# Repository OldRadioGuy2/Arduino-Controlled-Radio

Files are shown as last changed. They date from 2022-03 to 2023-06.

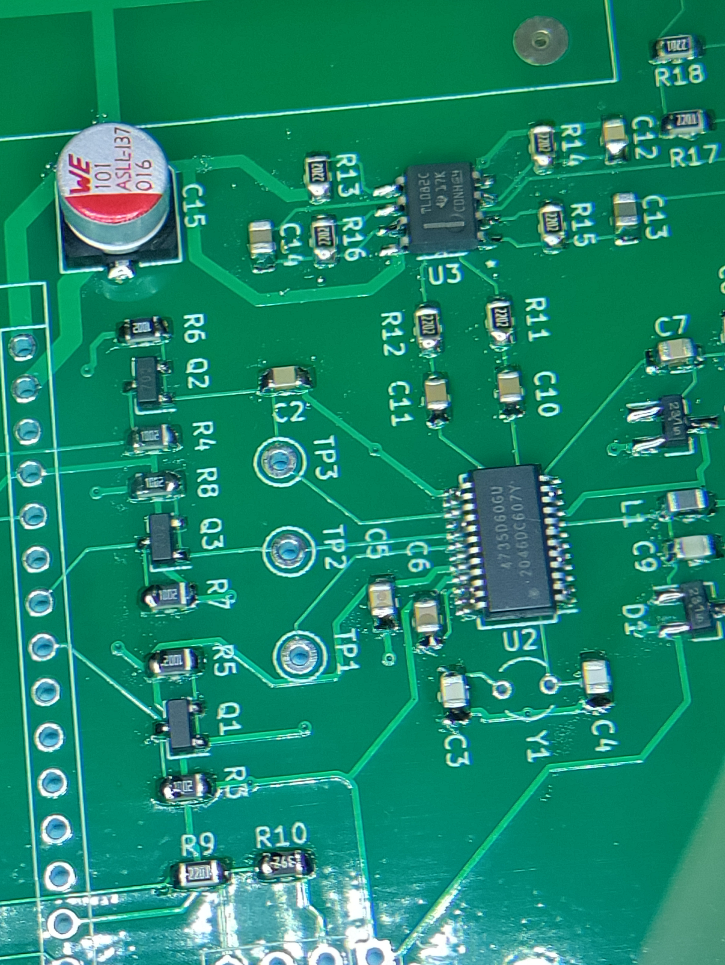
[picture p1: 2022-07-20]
Hardware/IMG_20220409_145141.jpg

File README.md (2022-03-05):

# Arduino-Controlled-Radio
An Arduino Controlled SI47xx Radio

This repository contains code and hardware design for an Arduino controlled radio based on the Skyworks SI47xx series of integrated radios, particularly the SI4735.

This particular implementation was concieved as a "behind the scenes" replacement for antique radio chassis that are too far gone for refurbishing. The idea is to use the Arduino to "read" the radio's original controls and translate their volume, tuning, and band settings to the SI chip. An NE55C is used to translate the tuning capacitor setting to a pulse width. A BLE Bluetooth module is included so that configuration, calibration, and remote control can be done using a smartphone application. Finally, the audio output is buffered for stero headphone use or amplified using an on-board LM1875 to drive a speaker.

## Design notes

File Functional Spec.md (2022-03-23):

# Arduino Controlled Radio Functional Specification
## Introduction
The Arduino Controlled Radio can be used for a variety of purposes but it's primary use case is to replace the electronics of a "worn out" vintage radio while
maintaining the radio's user controls. The Arduino determines the positions of the tuning capacitor, volume control, and band switch (if any) and translates them
into commands that are sent to the Si4735 AM/SW/FM receiver IC. The output of the IC is buffered for use with headphones or external stereo amplifier while an 
optional Class D amplifier module provides sufficient power to drive a modern speaker placed in the cabinet.

In addition to responding to the radios controls, the Arduino also monitors the serial port and a Bluetooth receiver for various commands so that the board can be configured and operated from a PC or Android/iPhone acting as a "remote control."

## Hardware
The hardware consists of the following major components:

- An Arduino Nano processor
- An HC-06 Bluetooth receiver
- A Skyworks SI4735 AM/SW/FM receiver IC
- A TL082 based stereo headphone buffer amplifier
- A TPA3118 based class D monophonic amplifier module (multi-sourced)

### Arduino Nano I/O
Arduino pins D3-D9 and A0-A3 are brought out to the board edge as I/O resources. An additional input is used to determine the position of the host radio's tuning dial by measuring value of the variable capacitor using an NE555C as a timer in one-shot mode with the capacitor controlling the pulse time. D13 triggers the one shot and A7 is used as a digital input to measure the pulse width.

D11(TxD out) and D12(RxD in) are used as a software serial port to communicate with the HC-06.

A4(SDIO) and A5(SCLK) are used as an I2C interface to the SI4735 while D2 is the  device reset.

### HC-06
The HC-06 is a slave only Bluetooth receiver with a serial interface that defaults to 9600 Baud. The module supports a limited AT command set. Of interest to us:

- **Set Name:**  *AT+NAMEnewname* sets the Bluetooth device name. This should return *OKnewname*
- **AT+PINxxxx:** *AT+PINxxxx* sets the pairing pin. This should return *OKxxxx*

### SI4735
The SI4735 is a general purpose single chip receiver with a number of features:  
  
- Worldwide FM band support (64–108 MHz)
- Worldwide AM band support (520–1710 kHz)
- SW band support (2.3–26.1 MHz)
- LW band support (153–279 kHz)
- Excellent real-world performance
- Freq synthesizer with integrated VCO
- Advanced seek tuning
- Automatic frequency control (AFC)
- Automatic gain control (AGC)
- Digital FM stereo decoder
- Programmable AVC max gain
- Programmable de-emphasis
- Seven selectable AM channel filters
- AM/FM/SW/LW digital tuning
- Programmable reference clock
- Volume control
- Adjustable soft mute control
- RDS/RBDS processor (Si4735)
- Optional digital audio out (Si4735)
- 2-wire and 3-wire control interface
- Wide range of ferrite loop sticks and
air loop antennas supported

It has an extensive programming command set which can be found here:
https://www.skyworksinc.com/-/media/Skyworks/SL/documents/public/application-notes/AN332.pdf

This project will use a (possibly modified) version of the interface library written in 2019 by Ricardo Lima Caratti.

## Software
The Software Consists of the following primary components:  
  
- **Setup:** Initializes the hardware, loads the stored configuration
- **Loop:** Performs the repetitive tasks needed to implement the following functionality:
    + **Check the tuner position (if enabled):** trigger and time the NE555C. Calculate the current position using the stored calibration points. If changed from last reading by more than the (band dependent) threshold, update the receiver frequency.
	+ **Check volume control (if enabled):** Read the configured Analog input and convert to position. If changed more than the threshold, update the volume.
	+ **Check the band switch (if enabled):** The bandswitch will be wired as a voltage divider so that each position will register a discrete voltage. Read the configured Analog input and convert to band #. Get the current band parameters from the configuration store.
	+ **Check the Arduino Serial Port for a command: ** If one was received call the *Command Processor*
	+ **If the Bluetooth receiver is paired, check its Serial Port for a command: ** If one was received call the *Command Processor*.
- **Command Processor:** Translates the received commands into actions. The key action classes are:
	+ **Get/Set SI4735 parameter:** Examples include changing frequency, volume, band, etc.
	+ **Get/Set Configuration Parameter:** Examples include defining bands, features used, etc.
	+ **Calibrate:** Determine physical to internal conversions such as NE555C pulse width vs tuner position, voltage values for band switch, etc.
- **Storage Manager** - Get/Set parameters in non-volatile storage.

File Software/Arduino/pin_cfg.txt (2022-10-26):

Using a Bus Pirate for a BLE modem.

Nano Pin D12 -  gray MOSI/TX
Nano Pin D11 - black MISO/RX
Nano Ground  - brown GND

Enter:
m
3 (serial)
5 (9600)
1 (8 bit)
1 (1 stop)
1 (idle high)
2 (normal output)
W (power supplies on)
P (outputs enable)
(1) (UART bridge)
y

Adafruit ILI9341 display connection:

Nano Pin D9 - Clk
Nano Pin D8 - MISO
Nano Pin D7 - MOSI
Nano Pin D6 - CS
Nano Pin D5 - D/C
Nano Pin D4 - Rst (optional)

Nano Pin VIN - 5 Volts for display

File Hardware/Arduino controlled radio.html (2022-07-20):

# /home/afinger/Dropbox/Projects/Arduino-Controlled-Radio/Hardware/Arduino controlled radio.sch

Thu 24 Mar 2022 08:08:10 PM EDT

Eeschema 5.1.5+dfsg1-2build2

Component Count:59

Ref | Qnty | Value | Part | Footprint | Description | Vendor
A1 | 1 | Arduino_BLE_Nano | MCU_Module:Arduino_Nano_v3.x | Module:Arduino_Nano | Arduino Nano v3.x
C1 | 1 | .01uF | Device:C_Small | Capacitor_SMD:C_0805_2012Metric_Pad1.18x1.45mm_HandSolder | Unpolarized capacitor, small symbol
C2 | 1 | 10nF | Device:C_Small | Capacitor_SMD:C_0805_2012Metric_Pad1.18x1.45mm_HandSolder | Unpolarized capacitor, small symbol
C3, C4 | 2 | 22pf | Device:C_Small | Capacitor_SMD:C_0805_2012Metric_Pad1.18x1.45mm_HandSolder | Unpolarized capacitor, small symbol
C5 | 1 | 100nf | Device:C_Small | Capacitor_SMD:C_0805_2012Metric_Pad1.18x1.45mm_HandSolder | Unpolarized capacitor, small symbol
C6 | 1 | 22nf | Device:C_Small | Capacitor_SMD:C_0805_2012Metric_Pad1.18x1.45mm_HandSolder | Unpolarized capacitor, small symbol
C7 | 1 | .47uF | Device:C_Small | Capacitor_SMD:C_0805_2012Metric_Pad1.18x1.45mm_HandSolder | Unpolarized capacitor, small symbol
C8 | 1 | 33pF | Device:C_Small | Capacitor_SMD:C_0805_2012Metric_Pad1.18x1.45mm_HandSolder | Unpolarized capacitor, small symbol
C9 | 1 | 6.8pF | Device:C_Small | Capacitor_SMD:C_0805_2012Metric_Pad1.18x1.45mm_HandSolder | Unpolarized capacitor, small symbol
C10, C11 | 2 | 1uF | Device:C_Small | Capacitor_SMD:C_0805_2012Metric_Pad1.15x1.40mm_HandSolder | Unpolarized capacitor, small symbol
C12 | 1 | .1uF | Device:C_Small | Capacitor_SMD:C_0805_2012Metric_Pad1.15x1.40mm_HandSolder | Unpolarized capacitor, small symbol
C13, C14 | 2 | 10uF | Device:C_Small | Capacitor_SMD:C_0805_2012Metric_Pad1.15x1.40mm_HandSolder | Unpolarized capacitor, small symbol
C15 | 1 | 100uF | Device:CP1_Small | Capacitor_SMD:C_Elec_6.3x5.4 | Polarized capacitor, small US symbol
C16 | 1 | .1 uF | Device:C_Small | Capacitor_SMD:C_0805_2012Metric_Pad1.15x1.40mm_HandSolder | Unpolarized capacitor, small symbol
D1, D2 | 2 | CM1213A-01SO | Power_Protection:CM1213A-01SO | Package_TO_SOT_SMD:SOT-23_Handsoldering | Single Channel ESD Protection Array
J1 | 1 | Jack-DC | Connector:Jack-DC | Arduino controlled radio:CUI_PJ-202B | DC Barrel Jack
J2 | 1 | Conn_02x15_Odd_Even | Connector_Generic:Conn_02x15_Odd_Even | Connector_PinHeader_2.54mm:PinHeader_2x15_P2.54mm_Vertical | Generic connector, double row, 02x15, odd/even pin numbering scheme (row 1 odd numbers, row 2 even numbers), script generated (kicad-library-utils/schlib/autogen/connector/)
J3, J6 | 2 | Conn_01x02 | Connector_Generic:Conn_01x02 | Connector_PinHeader_2.54mm:PinHeader_1x02_P2.54mm_Vertical | Generic connector, single row, 01x02, script generated (kicad-library-utils/schlib/autogen/connector/)
J4 | 1 | HC-06 Connector | Connector_Generic:Conn_01x04 | Connector_PinSocket_2.54mm:PinSocket_1x04_P2.54mm_Vertical | Generic connector, single row, 01x04, script generated (kicad-library-utils/schlib/autogen/connector/)
J5 | 1 | Conn_Coaxial | Connector:Conn_Coaxial | Arduino controlled radio:CUI_RCJ-045 | coaxial connector (BNC, SMA, SMB, SMC, Cinch/RCA, ...)
J7 | 1 | SJ1-3525NG | Arduino Controlled Radio:SJ1-3525NG | Arduino controlled radio:CUI_SJ1-3525NG
J8 | 1 | Speaker | Connector:Conn_Coaxial | Arduino controlled radio:CUI_RCJ-045 | coaxial connector (BNC, SMA, SMB, SMC, Cinch/RCA, ...)
JP1 | 1 | Ext/Loop Antenna | Jumper:Jumper_3_Bridged12 | Connector_PinHeader_2.54mm:PinHeader_1x03_P2.54mm_Vertical | Jumper, 3-pole, pins 1+2 closed/bridged
L1 | 1 | 150nH | Device:L | Inductor_SMD:L_0805_2012Metric_Pad1.15x1.40mm_HandSolder | Inductor
L2 | 1 | 4.7uH | Device:L | Inductor_SMD:L_0805_2012Metric_Pad1.15x1.40mm_HandSolder | Inductor
Q1, Q2, Q3 | 3 | 2N7002 | Transistor_FET:2N7002 | Package_TO_SOT_SMD:SOT-23 | 0.115A Id, 60V Vds, N-Channel MOSFET, SOT-23
R1 | 1 | 2.2k | Device:R_Small_US | Resistor_SMD:R_0805_2012Metric_Pad1.20x1.40mm_HandSolder | Resistor, small US symbol
R2 | 1 | 1Meg | Device:R_Small_US | Resistor_SMD:R_0805_2012Metric_Pad1.15x1.40mm_HandSolder | Resistor, small US symbol
R3, R4, R5, R6, R7, R8 | 6 | 10K | Device:R_Small_US | Resistor_SMD:R_0805_2012Metric_Pad1.15x1.40mm_HandSolder | Resistor, small US symbol
R9 | 1 | 2.2K | Device:R_Small_US | Resistor_SMD:R_0805_2012Metric_Pad1.15x1.40mm_HandSolder | Resistor, small US symbol
R10 | 1 | 3.8K | Device:R_Small_US | Resistor_SMD:R_0805_2012Metric_Pad1.15x1.40mm_HandSolder | Resistor, small US symbol
R11, R12, R13, R14, R15, R16 | 6 | 22K | Device:R_Small_US | Resistor_SMD:R_0805_2012Metric_Pad1.15x1.40mm_HandSolder | Resistor, small US symbol
R17, R18 | 2 | 1K | Device:R_Small_US | Resistor_SMD:R_0805_2012Metric_Pad1.15x1.40mm_HandSolder | Resistor, small US symbol
U1 | 1 | NE555 | Timer:NE555 | Arduino controlled radio:SOIC-8N | Precision Timers, DIP-8/SOIC-8
U2 | 1 | Si4735-D60-GU | RF_AM_FM:Si4735-D60-GU | Package_SO:SSOP-24_3.9x8.7mm_P0.635mm | AM/FM/SW/LW Broadcast Radio Receiver with RDS/RBDS
U3 | 1 | LM358 | Amplifier_Operational:LM358 | Arduino controlled radio:TL082CDR | Low-Power, Dual Operational Amplifiers, DIP-8/SOIC-8/TO-99-8
U4 | 1 | TPA3118AmplifierBoard | Arduino Controlled Radio:TPA3118AmplifierBoard | Arduino controlled radio:TPA3118_Board
Y1 | 1 | 32768KHz | Device:Crystal_Small | Crystal:Crystal_AT310_D3.0mm_L10.0mm_Vertical | Two pin crystal, small symbol

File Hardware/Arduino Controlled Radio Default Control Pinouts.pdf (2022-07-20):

Sheet1

## Arduino Controlled Radio Default Pinout

Connector Pins
Function Arduino Pin | Input
Tuning | | 27
Volume | A0 | 25 | Top of control to +5, bottom to GND, center to input
Band | A1 | 23

+5 pins are 18,22,26
GND pins are 2,4,5,6,10,12,14,16,20,24,28,30

Odd pins are nearest board edge

D13 Trigger
D10 Input

Top of control to +5, bottom to GND, wiper to input for 2 band, use voltage divider for multiple bands

Sheet1

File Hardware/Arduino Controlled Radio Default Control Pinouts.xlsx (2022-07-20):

Arduino Controlled Radio Default Pinout
 |  | Connector Pins
Function | Arduino Pin | Input
Tuning | D13 Trigger D10 Input | 27
Volume | A0 | 25 | Top of control to +5, bottom to GND, center to input
Band | A1 | 23 | Top of control to +5, bottom to GND, wiper to input for 2 band, use voltage divider for multiple bands
+5 pins are 18,22,26
GND pins are 2,4,5,6,10,12,14,16,20,24,28,30
Odd pins are nearest board edge

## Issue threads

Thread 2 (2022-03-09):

adding features for Arduino

LyleDriverGuy, 2022-03-09:
Reading a variable capacitor and controlling the receive frequency can be added to the main loop alongside the debug interface.

A global variable for new modes should be set and cleared with commands to the debug interface.  The mode can default to 'on' when it's ready to install.

The Bluetooth interface will share the serial port which will require changes to the debug interface.

OldRadioGuy2, 2022-03-10:
I need to update the schematic PDF for you. The Bluetooth is on a software serial port so no changes are needed for download and debug.

Agree on reading the cap. I think the main loop should be:
1. Check main serial port for command
2. Check the bluetooth for command
3. If enabled, check the capacitor position

There's a lot to control besides the frequency so we need to come up with a command set to access the chip functions via the SI4735 library.  Initially we can debug via the main serial port and then move to Bluetooth when the client is available.

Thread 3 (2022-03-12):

Audio Speaker Amplifier

OldRadioGuy2, 2022-03-12:
Going over the design once more, I realized that the LM1875 is not spec'ed below 16Volts so we can't expect much output. Some  alternatives:
1. Leave the amp off altogether and use an external unit or module. Downside: added cost expensive and need for additional power source.
2. Use a low voltage analog device like an LM386. Simple but downside is that you only get about 2Watts out at 12V
3. Use a Class D amp like a  TPA3111D1. Get good performance but design and board layout is more complicated to avoid noise issues.
4. Use a Class D amp module like: https://smile.amazon.com/gp/product/B07Q6RGVHQ. They seem to be multi-sourced from China but I'm not sure how stable the supply will be.

Thoughts? Any other alternatives?

lenlong36, 2022-03-13:
Alan,

Yes.  There are available inexpensive DC to DC converters that are very
small that you might be able to use. Amazon.com: ACEIRMC 3pcs XL6019 5A
High Power Current DC to DC Step-up 5V 6V 12V 24V 3-35V to 5-40V XL6019
Converter Adjustable Voltage Regulator Power Modules Boost Module Booster
(3pcs) : Electronics
<https://www.amazon.com/Aceirmc-Current-Converter-Adjustable-Regulator/dp/B082XQC2DS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>

Len

***@***.*** ***@***.***>*

On Fri, Mar 11, 2022 at 9:48 PM OldRadioGuy2 ***@***.***>
wrote:

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

OldRadioGuy2, 2022-03-14:
DC to DC converters and Class D amplifiers both risk introducing RF interference into the board. I've got some class D modules coming on Tuesday and I'll see whether they're a noise problem.

lenlong36, 2022-03-14:
It sure is a possibility.  I bought a 90vdc and 3vdc model and no noise on
the Hallicrafters receeiver.

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

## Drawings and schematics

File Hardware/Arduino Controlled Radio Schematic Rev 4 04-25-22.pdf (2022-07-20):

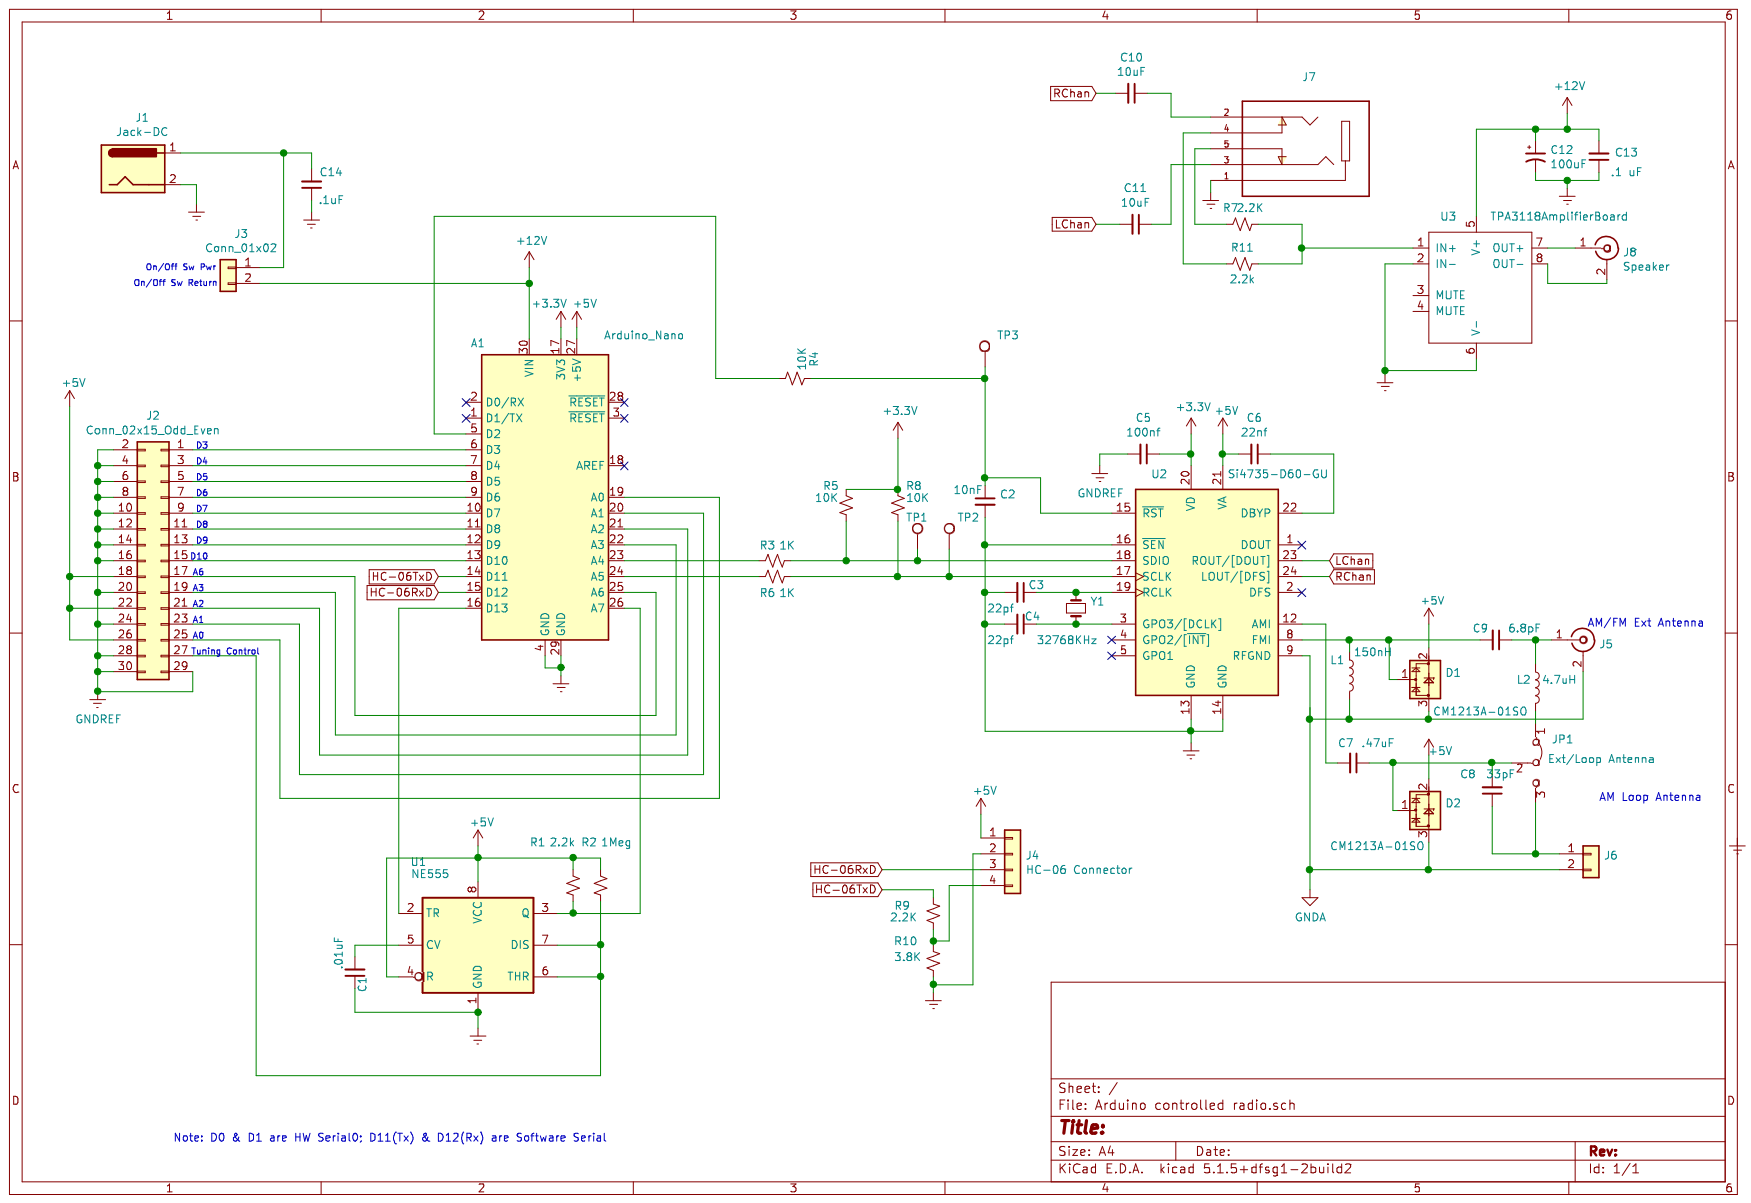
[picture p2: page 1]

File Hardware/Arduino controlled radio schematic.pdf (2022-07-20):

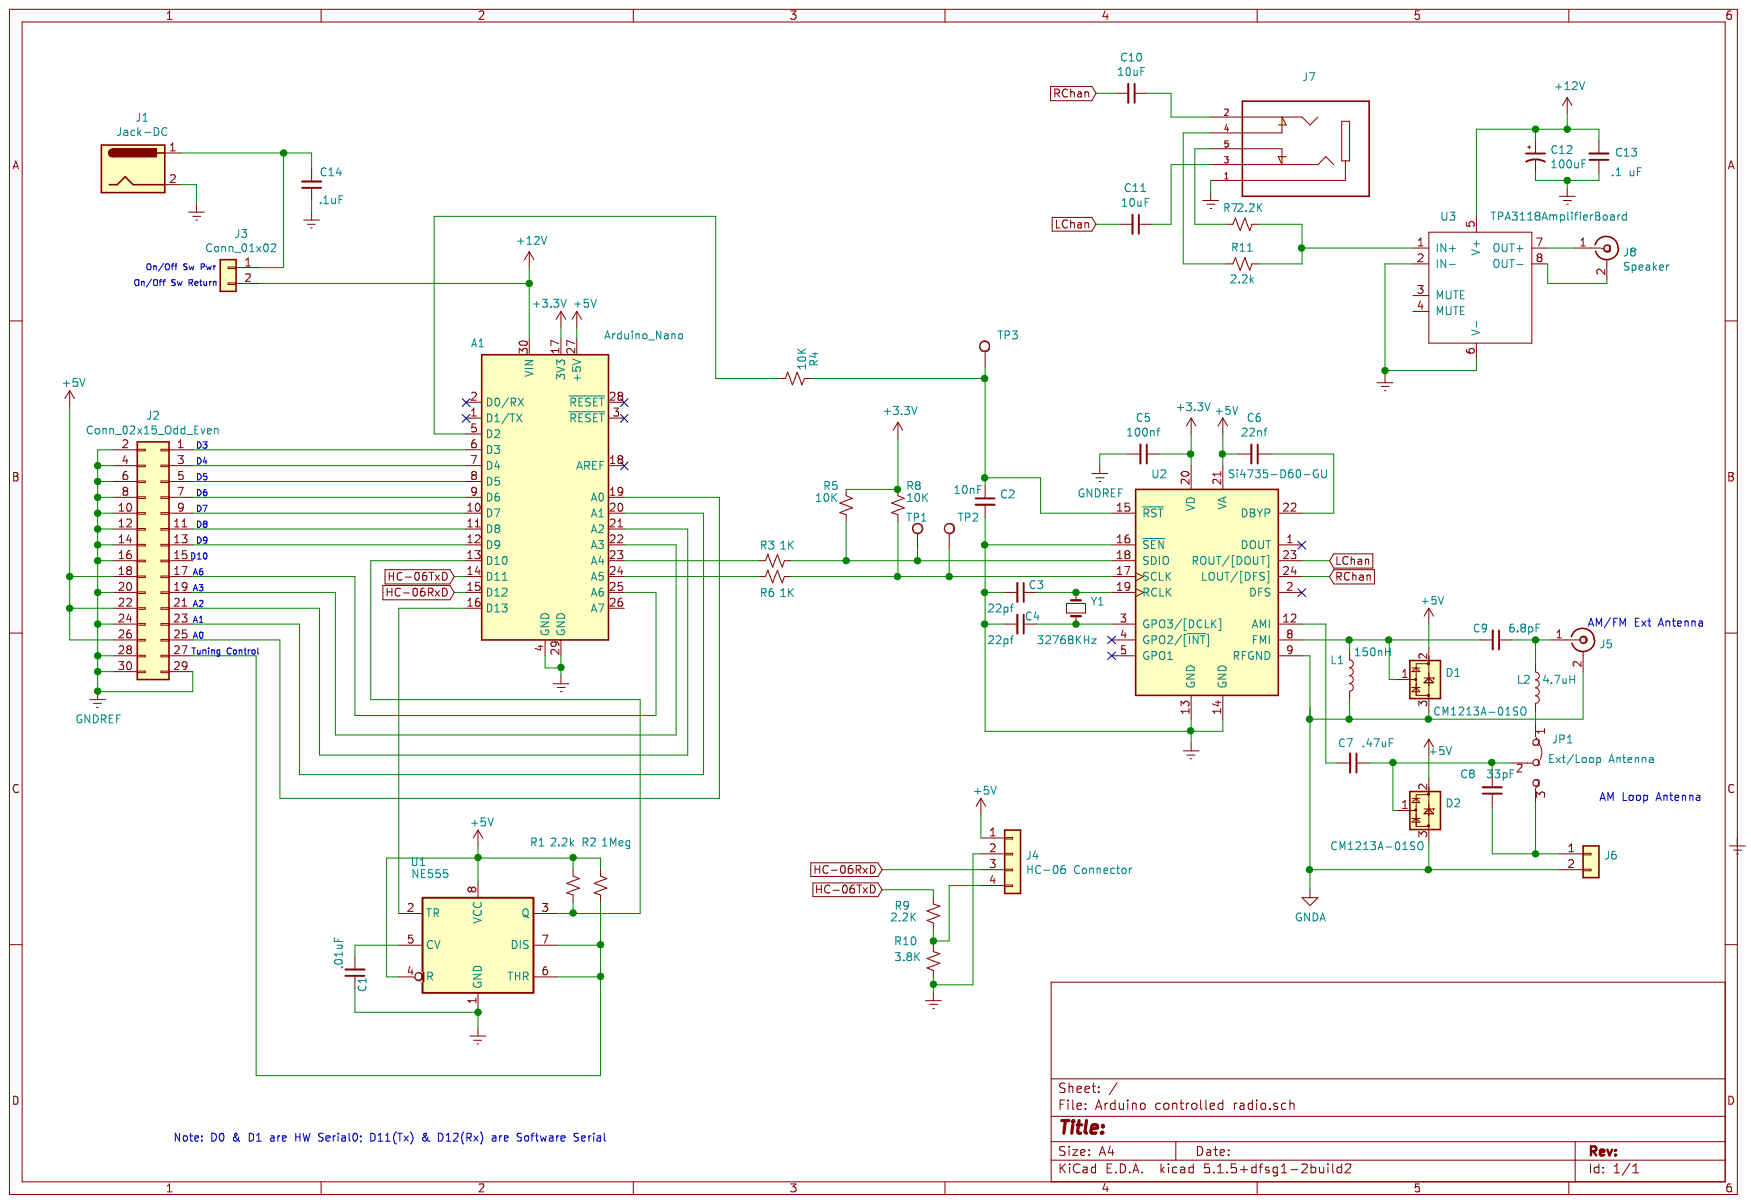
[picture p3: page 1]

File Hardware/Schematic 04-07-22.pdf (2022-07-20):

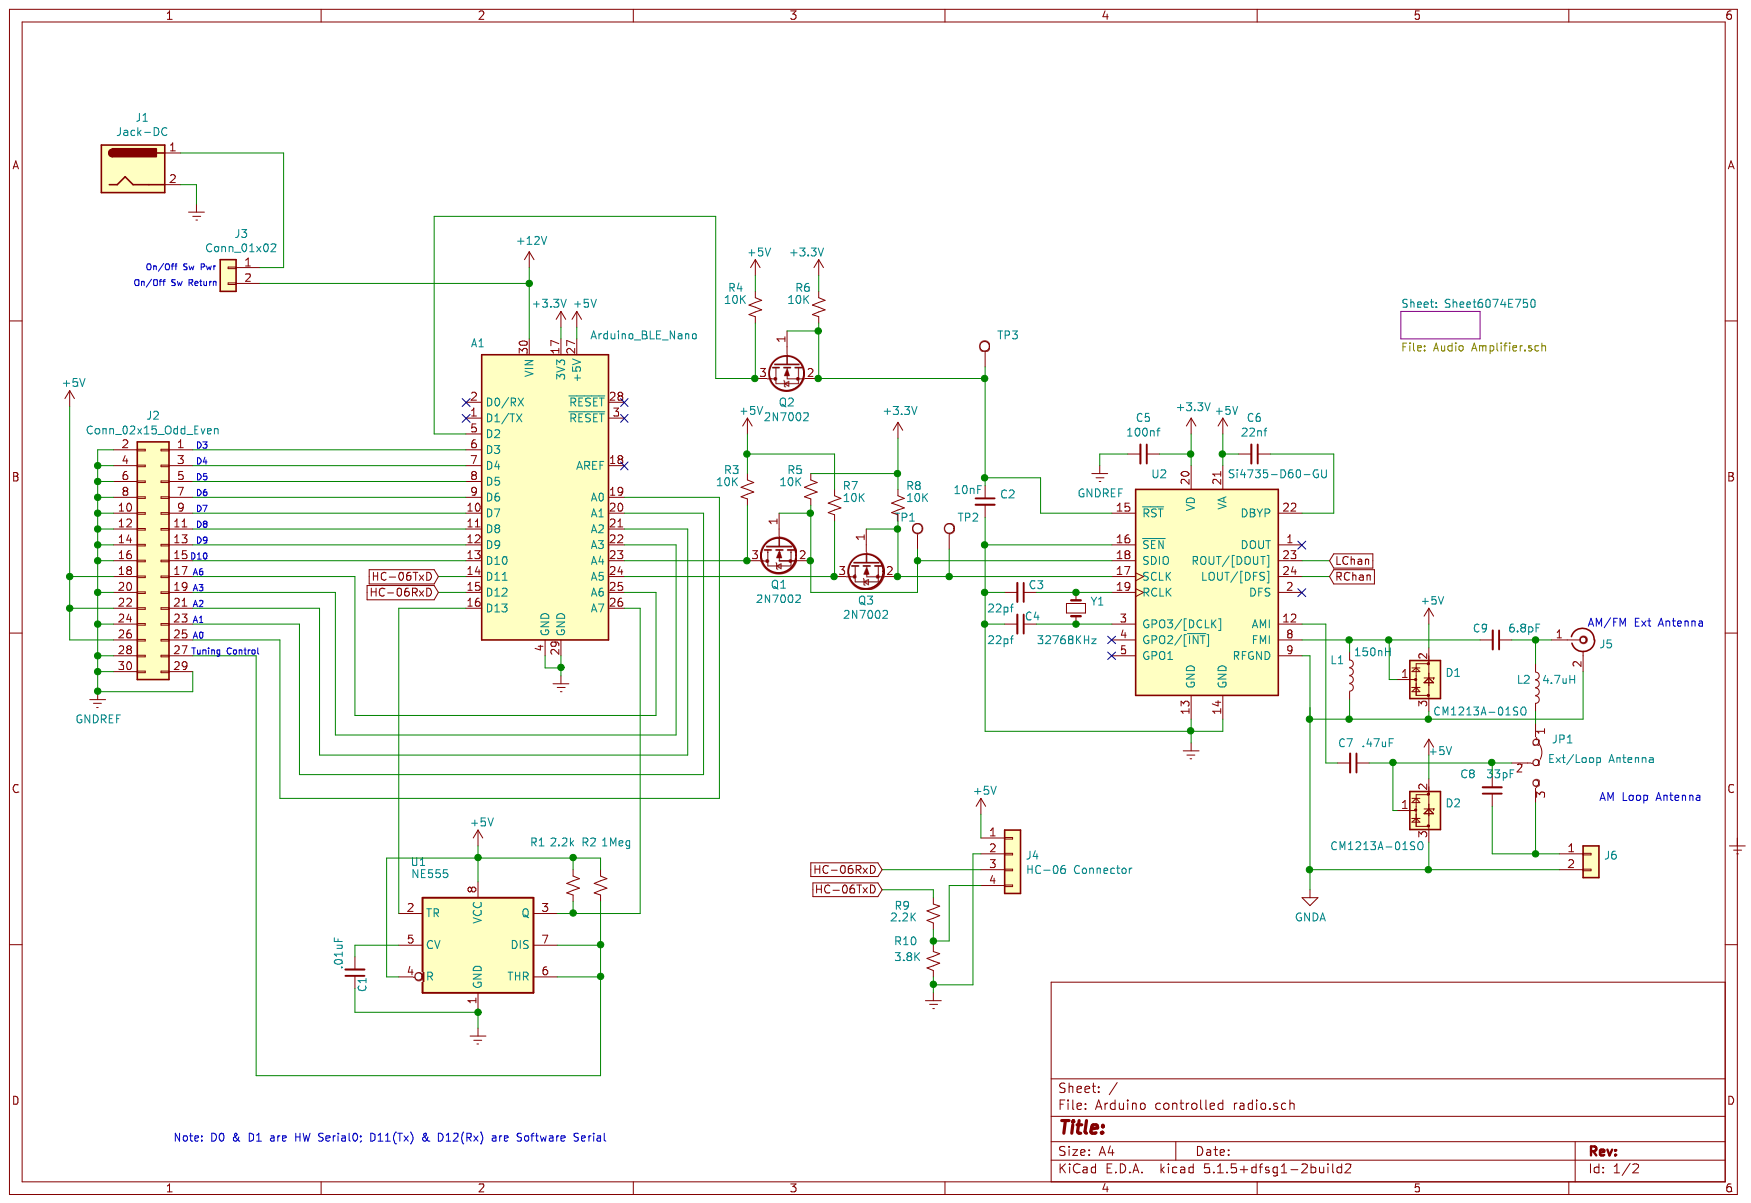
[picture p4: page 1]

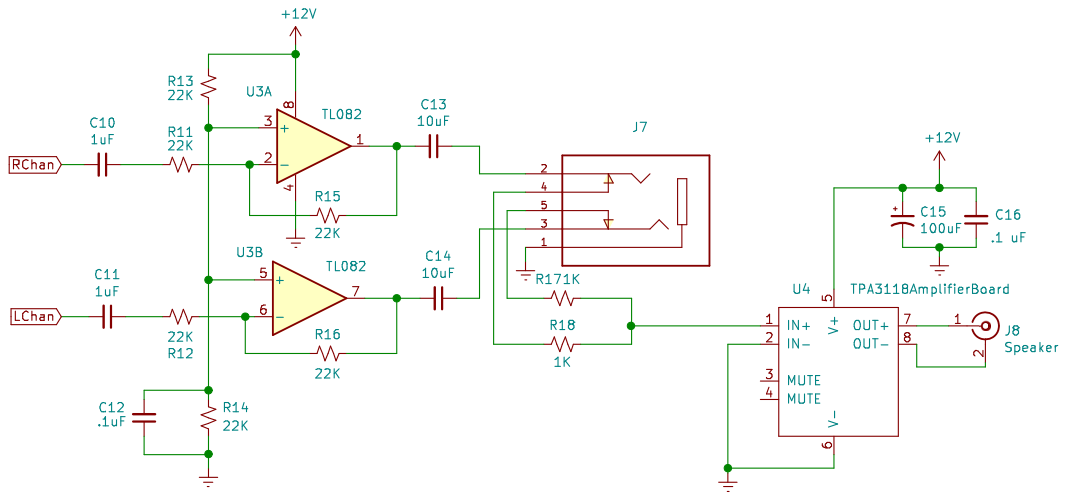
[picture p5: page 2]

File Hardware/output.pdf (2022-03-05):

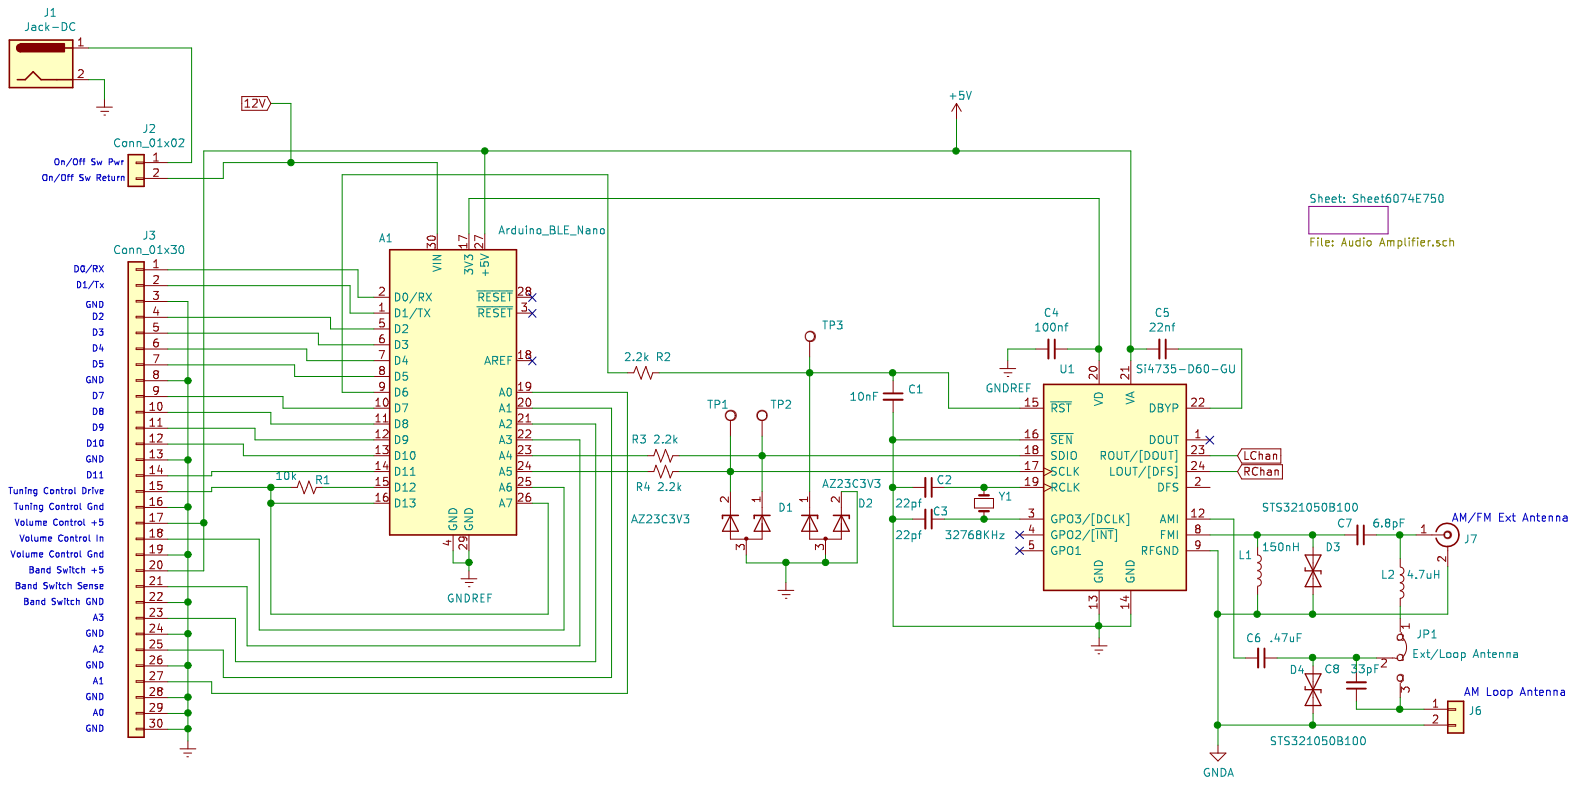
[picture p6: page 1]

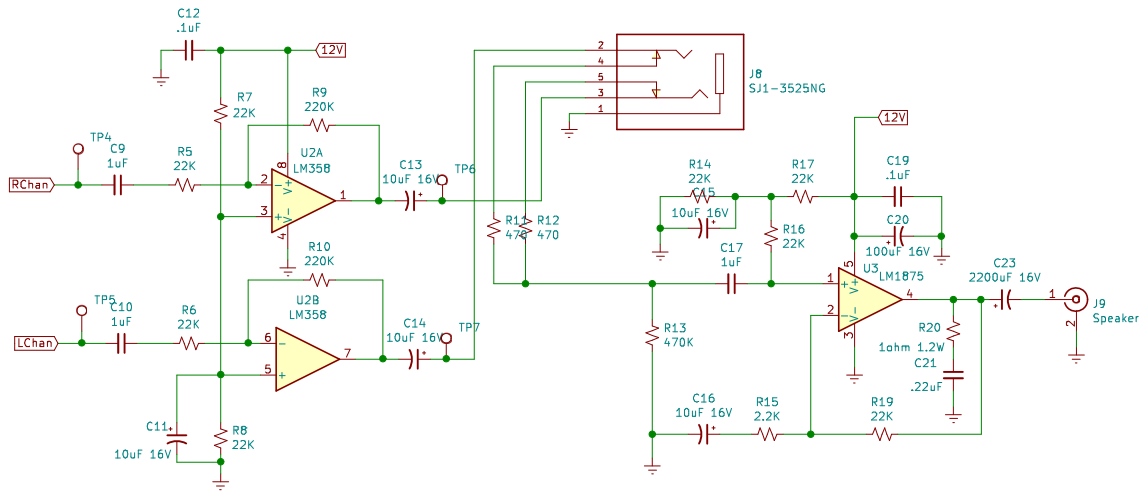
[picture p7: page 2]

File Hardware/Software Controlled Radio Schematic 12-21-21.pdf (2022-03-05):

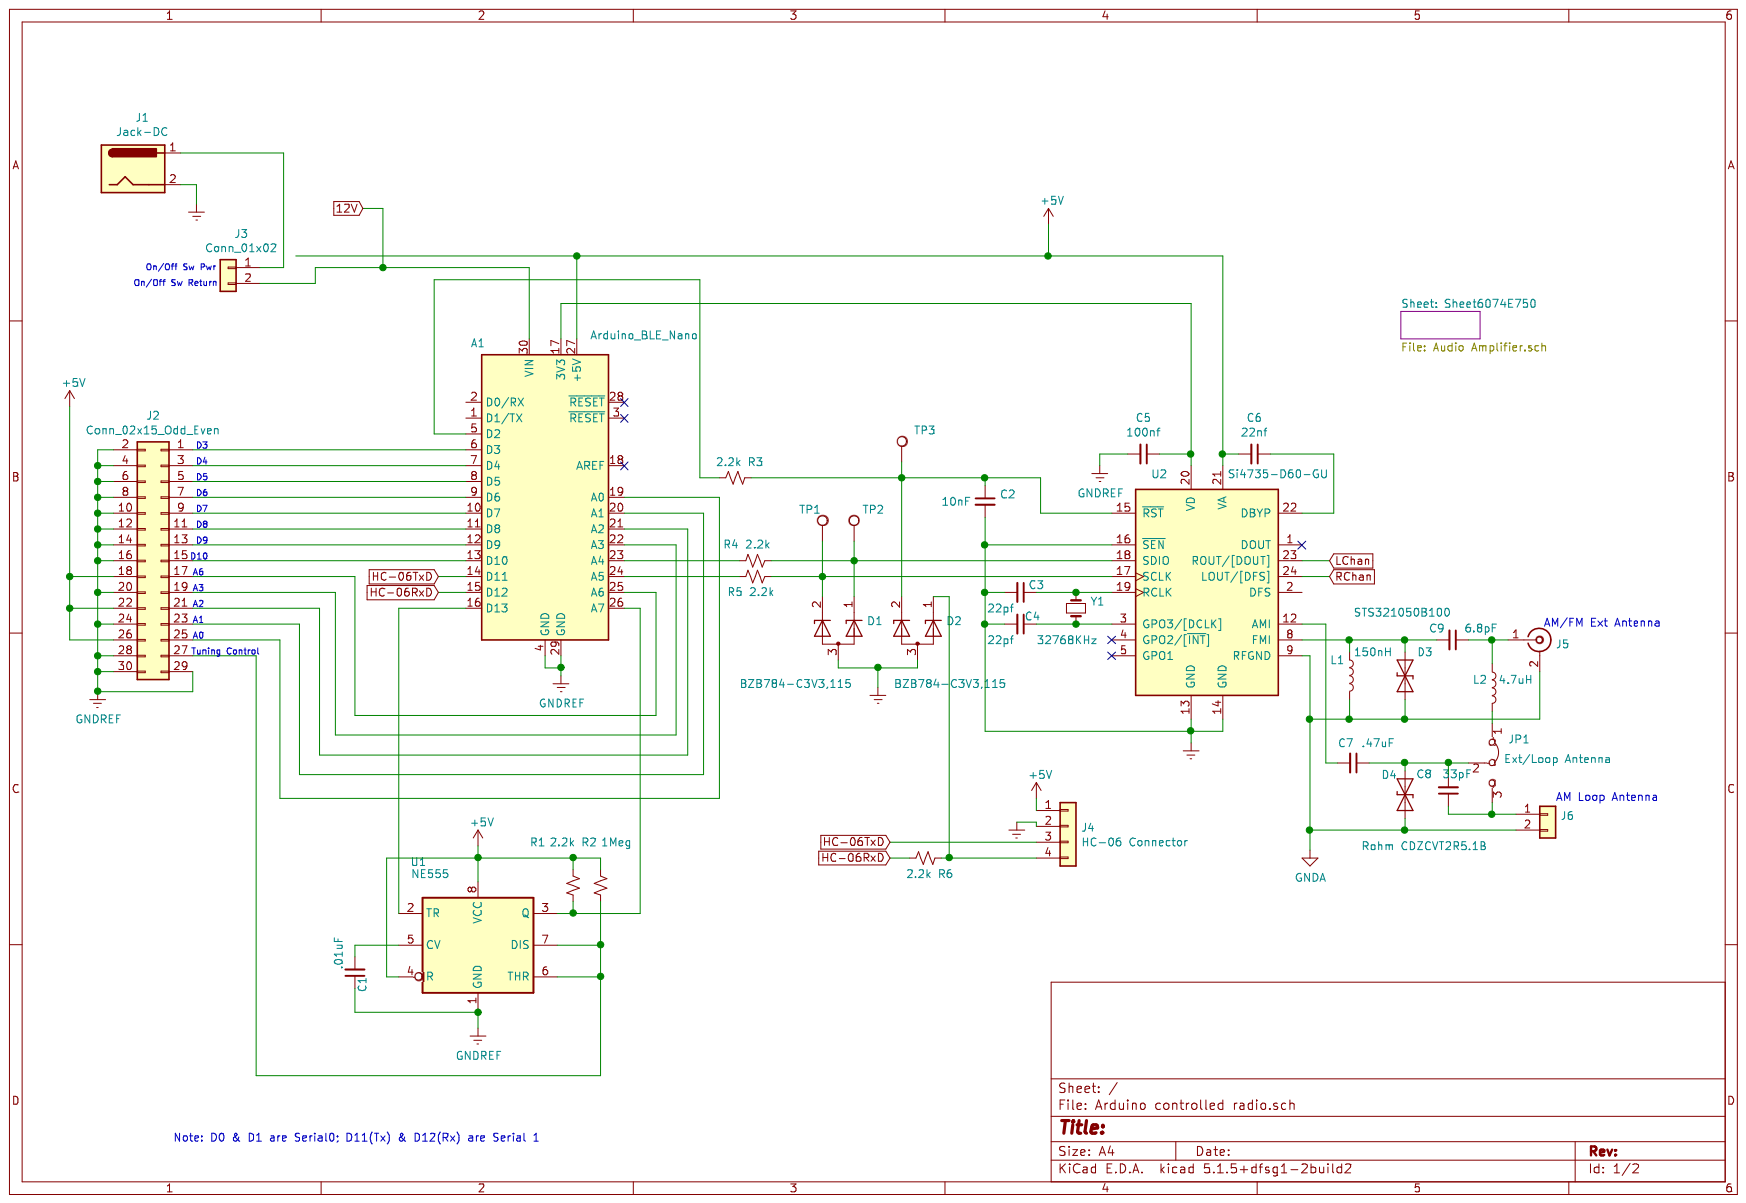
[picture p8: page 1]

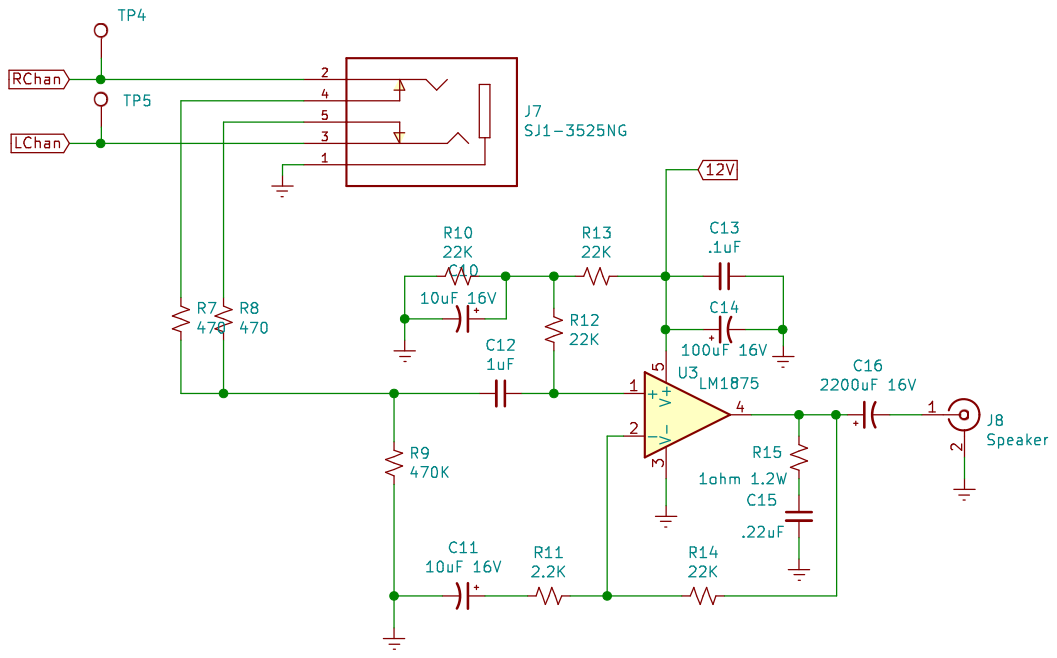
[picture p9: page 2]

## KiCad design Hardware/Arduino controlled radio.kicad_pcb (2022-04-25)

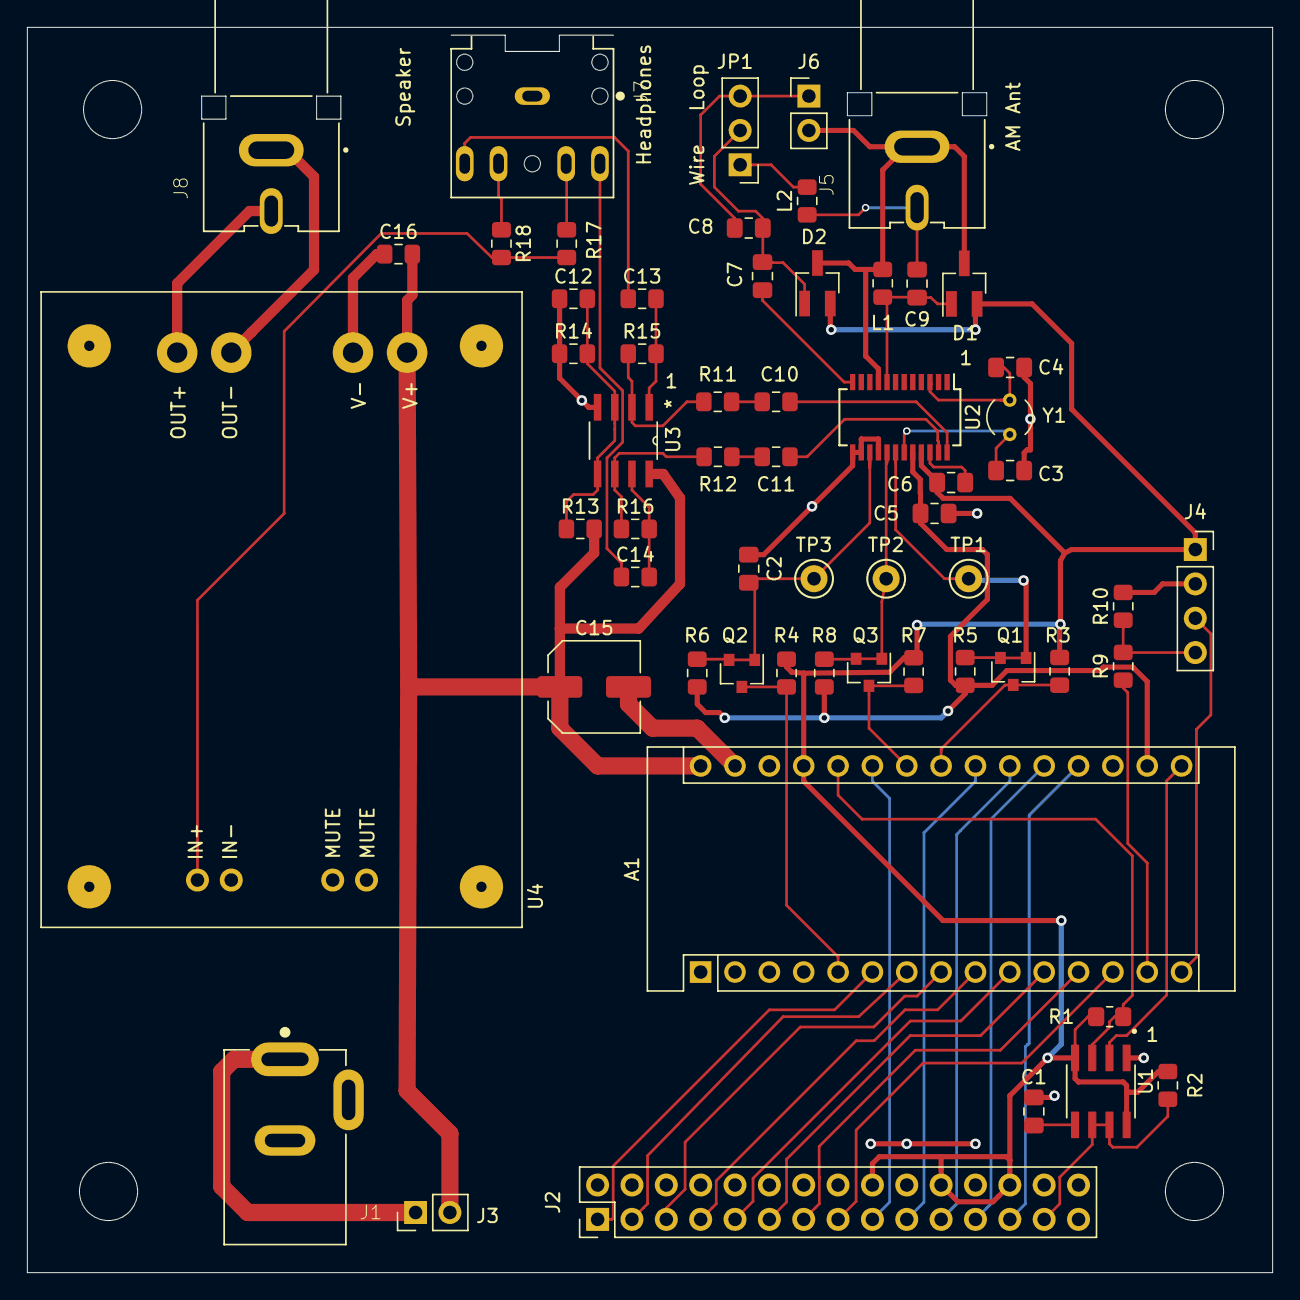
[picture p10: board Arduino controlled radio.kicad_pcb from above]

Board: 2 copper layers, 92.1 x 92.1 mm, 59 parts (0 on the bottom side), 57 nets.

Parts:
A1: Arduino_BLE_Nano; Arduino_Nano
C1: .01uF; C_0805_2012Metric_Pad1.18x1.45mm_HandSolder
C2: 10nF; C_0805_2012Metric_Pad1.18x1.45mm_HandSolder
C3, C4: 22pf; C_0805_2012Metric_Pad1.18x1.45mm_HandSolder
C5: 100nf; C_0805_2012Metric_Pad1.18x1.45mm_HandSolder
C6: 22nf; C_0805_2012Metric_Pad1.18x1.45mm_HandSolder
C7: .47uF; C_0805_2012Metric_Pad1.18x1.45mm_HandSolder
C8: 33pF; C_0805_2012Metric_Pad1.18x1.45mm_HandSolder
C9: 6.8pF; C_0805_2012Metric_Pad1.18x1.45mm_HandSolder
C10, C11: 1uF; C_0805_2012Metric_Pad1.15x1.40mm_HandSolder
C12: .1uF; C_0805_2012Metric_Pad1.15x1.40mm_HandSolder
C13, C14: 10uF; C_0805_2012Metric_Pad1.15x1.40mm_HandSolder
C15: 100uF; C_Elec_6.3x5.4
C16: .1 uF; C_0805_2012Metric_Pad1.15x1.40mm_HandSolder
D1, D2: CM1213A-01SO; SOT-23_Handsoldering
J1: Jack-DC; CUI_PJ-202B
J2: Conn_02x15_Odd_Even; PinHeader_2x15_P2.54mm_Vertical
J3, J6: Conn_01x02; PinHeader_1x02_P2.54mm_Vertical
J4: HC-06 Connector; PinSocket_1x04_P2.54mm_Vertical
J5: Conn_Coaxial; CUI_RCJ-045
J7: SJ1-3525NG; CUI_SJ1-3525NG
J8: Speaker; CUI_RCJ-045
JP1: Ext/Loop Antenna; PinHeader_1x03_P2.54mm_Vertical
L1: 150nH; L_0805_2012Metric_Pad1.15x1.40mm_HandSolder
L2: 4.7uH; L_0805_2012Metric_Pad1.15x1.40mm_HandSolder
Q1, Q2, Q3: 2N7002; SOT-23
R1: 2.2k; R_0805_2012Metric_Pad1.20x1.40mm_HandSolder
R2: 1Meg; R_0805_2012Metric_Pad1.15x1.40mm_HandSolder
R3, R4, R5, R6, R7, R8: 10K; R_0805_2012Metric_Pad1.15x1.40mm_HandSolder
R9: 2.2K; R_0805_2012Metric_Pad1.15x1.40mm_HandSolder
R10: 3.8K; R_0805_2012Metric_Pad1.15x1.40mm_HandSolder
R11, R12, R13, R14, R15, R16: 22K; R_0805_2012Metric_Pad1.15x1.40mm_HandSolder
R17, R18: 1K; R_0805_2012Metric_Pad1.15x1.40mm_HandSolder
TP1, TP2, TP3: TestPoint; TestPoint_Keystone_5000-5004_Miniature
U1: NE555; SOIC-8N
U2: Si4735-D60-GU; SSOP-24_3.9x8.7mm_P0.635mm
U3: LM358; TL082CDR
U4: TPA3118AmplifierBoard; TPA3118_Board
Y1: 32768KHz; Crystal_AT310_D3.0mm_L10.0mm_Vertical

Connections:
+3V3: A1.17, C5.1, R5.1, R6.1, R8.1, U2.20
+5V: A1.27, C6.2, D1.2, D2.2, J2.18, J2.22, J2.26, J4.1, R1.1, R2.1, R3.1, R4.1, R7.1, U1.4, U1.8, U2.21
+12V: A1.30, C15.1, C16.2, J3.2, R13.2, U3.8, U4.5
GNDA: D1.3, D2.3, J5.2, J6.2, L1.2, U2.9
GNDREF: A1.4, A1.29, C1.1, C2.2, C3.2, C4.2, C5.2, C12.1, C15.2, C16.1, J1.2, J2.2, J2.4, J2.6, J2.8, J2.10, J2.12, J2.14, J2.16, J2.20, J2.24, J2.28, J2.29, J2.30, J4.2, J7.1, R10.2, R14.1, U1.1, U2.13, U2.14, U2.16, U3.4, U4.2, U4.6
HC-06RxD: A1.15, J4.3
HC-06TxD: A1.14, R9.1
LChan: C11.2, U2.23
unnamed: A1.5, Q2.3, R4.2
unnamed: A1.6, J2.1
unnamed: A1.7, J2.3
unnamed: A1.8, J2.5
unnamed: A1.9, J2.7
unnamed: A1.10, J2.9
unnamed: A1.11, J2.11
unnamed: A1.12, J2.13
unnamed: A1.13, J2.15
unnamed: A1.16, U1.2
unnamed: A1.19, J2.25
unnamed: A1.20, J2.23
unnamed: A1.21, J2.21
unnamed: A1.22, J2.19
unnamed: A1.23, Q1.3, R3.2
unnamed: A1.24, Q3.3, R7.2
unnamed: A1.25, J2.17
unnamed: A1.26, R1.2, U1.3
unnamed: C1.2, U1.5
unnamed: C2.1, Q2.1, Q2.2, R6.2, TP3.1, U2.15
unnamed: C3.1, U2.19, Y1.1
unnamed: C4.1, U2.3, Y1.2
unnamed: C6.1, U2.22
unnamed: C7.1, C8.2, D2.1, JP1.2
unnamed: C7.2, U2.12
unnamed: C8.1, J6.1, JP1.3
unnamed: C9.1, J5.1, L2.1
unnamed: C9.2, D1.1, L1.1, U2.8
unnamed: C10.1, R11.1
unnamed: C11.1, R12.1
unnamed: C12.2, R13.1, R14.2, U3.3, U3.5
unnamed: C13.1, J7.2
unnamed: C13.2, R15.2, U3.1
unnamed: C14.1, J7.3
unnamed: C14.2, R16.2, U3.7
unnamed: J1.1, J3.1
unnamed: J2.27, R2.2, U1.6, U1.7
unnamed: J4.4, R9.2, R10.1
unnamed: J7.4, R18.1
unnamed: J7.5, R17.1
unnamed: J8.1, U4.7
unnamed: J8.2, U4.8
unnamed: JP1.1, L2.2
unnamed: Q1.1, Q1.2, R5.2, TP1.1, U2.18
unnamed: Q3.1, Q3.2, R8.2, TP2.1, U2.17
unnamed: R11.2, R15.1, U3.2
unnamed: R12.2, R16.1, U3.6
unnamed: R17.2, R18.2, U4.1
RChan: C10.2, U2.24

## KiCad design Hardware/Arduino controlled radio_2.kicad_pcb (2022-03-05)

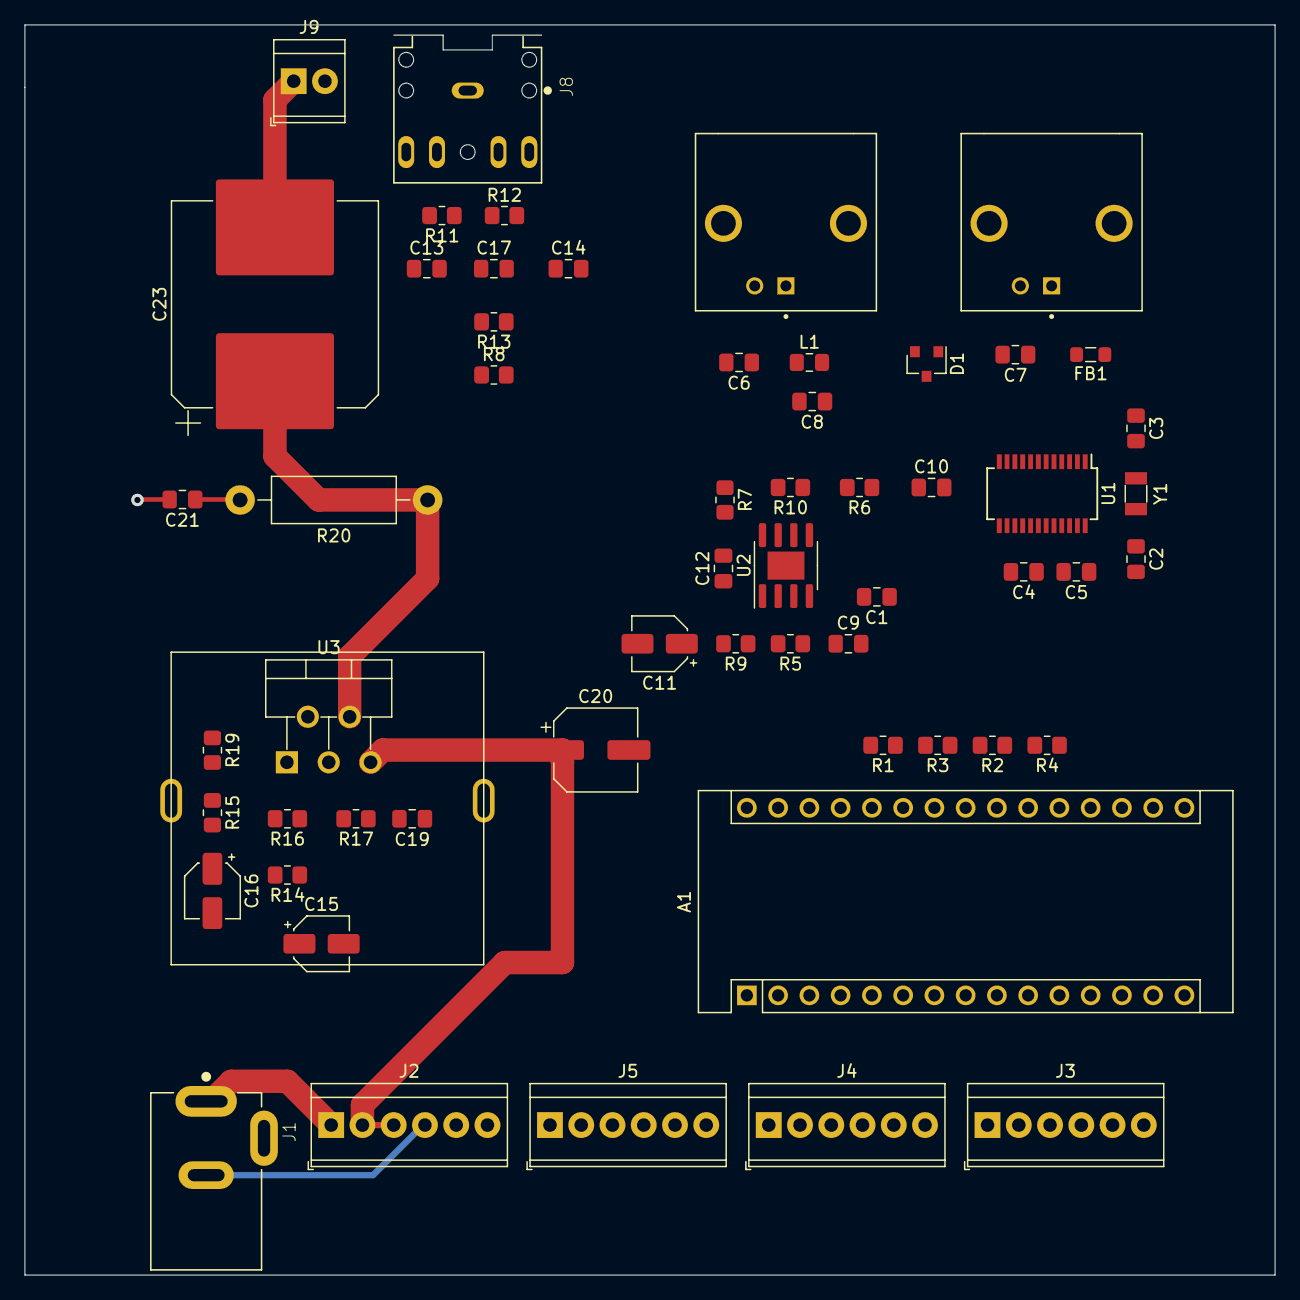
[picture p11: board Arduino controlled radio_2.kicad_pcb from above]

Board: 2 copper layers, 101.6 x 101.6 mm, 57 parts (0 on the bottom side), 48 nets.

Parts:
A1: Arduino_BLE_Nano; Arduino_Nano
C1: 10nF; C_0805_2012Metric_Pad1.18x1.45mm_HandSolder
C2, C3: 22pf; C_0805_2012Metric_Pad1.18x1.45mm_HandSolder
C4: 100nf; C_0805_2012Metric_Pad1.18x1.45mm_HandSolder
C5: 22nf; C_0805_2012Metric_Pad1.18x1.45mm_HandSolder
C6, C8: 3.3pF; C_0805_2012Metric_Pad1.18x1.45mm_HandSolder
C7: 6.8pF; C_0805_2012Metric_Pad1.18x1.45mm_HandSolder
C9, C10, C12, C13, C14, C19: .1uF; C_0805_2012Metric_Pad1.18x1.45mm_HandSolder
C11, C15, C16: 10uF 16V; CP_Elec_4x5.3
C17: 1uF; C_0805_2012Metric_Pad1.18x1.45mm_HandSolder
C20: 100uF 50V; CP_Elec_6.3x7.7
C21: .22uF; C_0805_2012Metric_Pad1.18x1.45mm_HandSolder
C23: 2200uF 16V; CP_Elec_16x17.5
D1: SP0502BAHT; SOT-23
FB1: Ferrite_Bead_Small; L_0805_2012Metric_Pad1.05x1.20mm_HandSolder
J1: Jack-DC; CUI_PJ-202B
J2, J3, J4, J5: Screw_Terminal_01x06; TerminalBlock_TE_282834-6_1x06_P2.54mm_Horizontal
J6, J7: Conn_Coaxial; CONN_1-1337543-0
J8: SJ1-3525NG; CUI_SJ1-3525NG
J9: Screw_Terminal_01x02; TerminalBlock_TE_282834-2_1x02_P2.54mm_Horizontal
L1: 10nH; L_0805_2012Metric_Pad1.15x1.40mm_HandSolder
R1: 10k; R_0805_2012Metric_Pad1.20x1.40mm_HandSolder
R2, R3, R15: 4.7K; R_0805_2012Metric_Pad1.20x1.40mm_HandSolder
R4: 10K; R_0805_2012Metric_Pad1.20x1.40mm_HandSolder
R5, R6, R7, R8, R14, R16, R17: 22K; R_0805_2012Metric_Pad1.20x1.40mm_HandSolder
R9, R10: 220K; R_0805_2012Metric_Pad1.20x1.40mm_HandSolder
R11, R12: 470; R_0805_2012Metric_Pad1.20x1.40mm_HandSolder
R13: 1Meg; R_0805_2012Metric_Pad1.20x1.40mm_HandSolder
R19: 470K; R_0805_2012Metric_Pad1.20x1.40mm_HandSolder
R20: 1ohm 1.2W; R_Axial_DIN0411_L9.9mm_D3.6mm_P15.24mm_Horizontal
U1: Si4735-D60-GU; SSOP-24_3.9x8.7mm_P0.635mm
U2: LM358; SOIC-8-1EP_3.9x4.9mm_P1.27mm_EP2.29x3mm
U3: LM1875; TO-220-5_P3.4x3.7mm_StaggerOdd_Lead3.8mm_Vertical
Y1: 32768KHz; Crystal_SMD_3215-2Pin_3.2x1.5mm

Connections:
12V: A1.30, C12.2, C19.2, C20.1, J2.2, J2.3, J2.5, R7.2, R17.1, U2.8, U3.5
+5V: A1.27, C5.2, J4.3, J5.1, J5.4, U1.21
GNDREF: A1.4, A1.29, C1.2, C2.2, C3.2, C4.2, C11.2, C12.1, C15.2, C16.2, C19.1, C20.2, C21.2, D1.3, J1.2, J2.4, J2.6, J3.6, J4.2, J4.5, J4.6, J5.3, J5.6, J8.1, J9.2, R8.1, R13.2, R14.2, U1.13, U1.14, U2.4, U3.3
LChan: C10.2, U1.23
unnamed: A1.9, R4.2
unnamed: A1.10, J3.1
unnamed: A1.11, J3.2
unnamed: A1.12, J3.3
unnamed: A1.13, J3.4
unnamed: A1.14, J3.5
unnamed: A1.15, R1.1
unnamed: A1.16, A1.26, J4.1, R1.2
unnamed: A1.17, C4.1, R2.1, R3.1, U1.20
unnamed: A1.21, J5.5
unnamed: A1.22, J5.2
unnamed: A1.23, R2.2, U1.18
unnamed: A1.24, R3.2, U1.17
unnamed: A1.25, J4.4
unnamed: C1.1, R4.1, U1.15
unnamed: C2.1, U1.19, Y1.1
unnamed: C3.1, U1.3, Y1.2
unnamed: C5.1, U1.22
unnamed: C6.1, L1.1, U1.12
unnamed: C6.2, C7.2, C8.2, J6.2, J7.2, U1.9
unnamed: C7.1, FB1.2, U1.8
unnamed: C8.1, D1.2, J6.1, L1.2
unnamed: C9.1, R5.1
unnamed: C10.1, R6.1
unnamed: C11.1, R7.1, R8.2, U2.3, U2.5
unnamed: C13.1, J8.2
unnamed: C13.2, R9.2, U2.1
unnamed: C14.1, J8.3
unnamed: C14.2, R10.2, U2.7
unnamed: C15.1, R14.1, R16.1, R17.2
unnamed: C16.1, R15.2
unnamed: C17.1, R16.2, U3.1
unnamed: C17.2, R11.1, R12.1, R13.1
unnamed: C21.1, R20.2
unnamed: C23.1, R19.1, R20.1, U3.4
unnamed: C23.2, J9.1
unnamed: D1.1, FB1.1, J7.1
unnamed: J1.1, J2.1
unnamed: J8.4, R11.2
unnamed: J8.5, R12.2
unnamed: R5.2, R9.1, U2.2
unnamed: R6.2, R10.1, U2.6
unnamed: R15.1, R19.2, U3.2
RChan: C9.2, U1.24

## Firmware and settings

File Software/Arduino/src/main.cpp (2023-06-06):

/*
Software Controlled Radio - Arduino Main

This is the main entry point for the Arduino code. It's derived from the 8735 
test code (SI4735_01_POC.cpp) and library written by Ricardo Lima Caratti (Nov 2019).

   The table below shows the Si4735 and Arduino Pro Mini pin connections 
    
    | Si4735 pin      |  Arduino Pin  |
    | ----------------| ------------  |
    | RESET (pin 15)  |     2 (was 12)|
    | SDIO (pin 18)   |     A4        |
    | CLK (pin 17)   |     A5         |

*/

#include "select_build.h"
#ifdef BUILD_APPLICATION

#include "arduino_radio.h"
#include "commands.h"

#if BUILD_GUI_LIB
#include "Adafruit_GFX.h"
#include "Adafruit_ILI9341.h"
# define TFT_RST  4
# define TFT_DC   5
# define TFT_CS   6
# define TFT_MOSI 7
# define TFT_MISO 8
# define TFT_CLK  9
Adafruit_ILI9341 tft = Adafruit_ILI9341(TFT_CS, TFT_DC, TFT_MOSI, TFT_CLK, TFT_RST, TFT_MISO);

#include "display.h"
#endif

#if BUILD_RADIO
# define RESET_PIN 2

const char * const strBandwidthAM[NUM_BW_DEF_AM] = {
    "6", "4", "3", "2", "1", "1.8", "2.5"
};
/* units are KHz for AM bands */
const FREQ_VAL bandwidthAM[NUM_BW_DEF_AM] = {
    6,  4,  3,  2,  1,  1, 1
};
/* and 10's of KHz for FM */
const FREQ_VAL bandwidthFM[NUM_BW_DEF_FM] = {
    0, 11, 8, 6, 4
};

/* single global instance of the Radio control library class */
SI4735 rx;
#endif

#define CMD_BUF_SIZE 40

#if SOFT_SERIAL
# include <SoftwareSerial.h>

SoftwareSerial BLE_Serial (BLE_RxPin, BLE_TxPin);

char ble_cmd_buffer[CMD_BUF_SIZE];
#endif

char dbg_cmd_buffer[CMD_BUF_SIZE];

char fmt_rsp_buffer[RSP_BUF_SIZE];

/* Arduino defined entry point.
 * do some initialization */
void setup(void)
{
  Serial.begin(9600);

#if BUILD_RADIO
  pinMode( RESET_PIN, OUTPUT);
  digitalWrite(RESET_PIN, HIGH);
#endif

#if SOFT_SERIAL
    pinMode(BLE_RxPin, INPUT);
    pinMode(BLE_TxPin, OUTPUT);

    BLE_Serial.begin (9600);
#endif

  pinMode( triggerPin, OUTPUT);     // output to trigger 555 timer
  pinMode( pulseInPin, INPUT);      // pulse input
  digitalWrite(triggerPin, HIGH);
  
  Serial.println(F("Arduino Controlled Radio."));
#if BUILD_GUI_LIB
  tft.begin();
#endif
#if SOFT_SERIAL
    BLE_Serial.println(F("Hello"));
#endif
#if BUILD_RADIO
// Look for the Si47XX I2C bus address
  rx.setI2CStandardMode();
  int16_t si4735Addr = rx.getDeviceI2CAddress(RESET_PIN);
  if ( si4735Addr == 0 ) {
    Serial.println(F("Si473X not found!"));
    Serial.flush();
    while (1);
  } 

    Serial.print(F("The Si473X I2C address is 0x"));
    Serial.println(si4735Addr, HEX);
    rx.setup(RESET_PIN, 0); // FM_FUNCTION);
    // rx.setup(RESET_PIN, -1, 1, SI473X_ANALOG_AUDIO);
    // Starts defaul radio function and band (FM; from 84 to 108 MHz; 103.9 MHz; step 100kHz)
#endif

/* Analog refrence for A to D */
    // if (globalConfig.featureEn[FEATURE_VOLUME])
    pinMode(analogVolumePin, INPUT);
#if PLATFORM == NANO_ATMEGA_BOARD
    analogReference( DEFAULT );
#endif
#if PLATFORM == NANO_BLE_BOARD
    analogReference( AR_INTERNAL2V4 );
#endif
}

const command command_list []= {
    {"SF", & set_freq },    // Set Frequency: SF,float_frequency (KHz)
    {"SB", & set_band },    // Set Band: SB,float_lower_limit, float_upper_limit 
    {"SV", & set_volume },  // write the configuration
    {"EV", & volume_feature },    // turn on/off analog volume feature
    {"ET", & tuning_feature },   // turn on/off tuning cap feature
    {"EB", & band_sw_feature },    // turn on/off analog band sw feature
    {"ED", & display_feature },   // turn on/off writing display feature
    {"GS", & get_sig_lvl },    // Get Current Frequency: GF. Returns float frequency in KHz
    {"GB", & get_band },    // Get Current Frequency: GF. Returns float frequency in KHz
    {"GV", & get_volume },    // Get Current Frequency: GF. Returns float frequency in KHz
    {"GF", & get_freq },    // Get Current Frequency: GF. Returns float frequency in KHz
    {"WR", & save_cfg },    // write the configuration
    {"MB", & create_band }, // 
    {"DB", & delete_band }, // 
    {"CT", & calibrate_tuner }, // 
    {"CB", & calibrate_band }, // 
    {"CP", & read_Cap }     // read the analog Cap
};
const char szOn[] = "On";
const char szOff[] = "Off";

void print_help(void)
{
    unsigned int i = 0;
    Serial.print( F("Commands are : ") );
    do
    {
        Serial.write( command_list[i].cmd );
        i ++;
        if ( i >= sizeof(command_list) / sizeof(command))
            break;
        Serial.print( F(", ") );
    } while (1);
    Serial.print( F("\n") );
}

CHAR BLE_command = 0;
CHAR cur_Mode = MODE_NOT_VALID;

const char * process_cmd_line(char is_ble)
{
    char * cmd_buffer;
    unsigned int i = 0;
#if SOFT_SERIAL
    if (is_ble)
        cmd_buffer = ble_cmd_buffer;
    else
#endif
        cmd_buffer = dbg_cmd_buffer;

    fmt_rsp_buffer[0] = '\0';
    BLE_command = is_ble;

    if (('?' == cmd_buffer[0]) &&
        (0 == is_ble))
    {
        print_help();
        return "";
    }
    do  {
        const command * cPtr = & command_list[i];
        if ((cPtr->cmd[0] == cmd_buffer[0]) &&
            (cPtr->cmd[1] == cmd_buffer[1]) )
            return cPtr->processor(cmd_buffer);
        i ++;
    } while ( i < sizeof(command_list) / sizeof(command));
    return " not found";    // " -1";
}

CHAR forceBand = 0;
BOOL prev_mode_valid = false;
BOOL mode_is_valid = false;

#if BUILD_GUI_LIB
 UINT  dispFreq = 999;
 uint8_t curRotate = 255;
 void myText(int line);
 int dbgText(int line);
#endif

/* Arduino defined entry point, like main ()
 * don't return */
void loop(void)
{
    int dbg_cmd_in = 0; // start with empty buffer
#if SOFT_SERIAL
    int ble_cmd_in = 0; // start with empty buffer
#endif
    uint8_t chRd;
#if BUILD_GUI_LIB
    uint8_t scr_line = 0;
    uint8_t scr_need_up = 0;
#endif
#if BUILD_RADIO
    CHAR curBand = NUM_BANDS;
    UCHAR curVol = 255;
    UINT currentFrequency = 0;
#endif
    load_config();

    Serial.print(F("Read Frequency Cap: "));
    Serial.println( (globalConfig.featureEn[FEATURE_FREQ_CAP]) ? szOn : szOff);
    chRd = globalConfig.featureEn[FEATURE_VOLUME];
    Serial.print(F("Read Analog Volume: "));
        if ((3 == chRd) || (6 == chRd))
        Serial.println(F("rev-log."));
    else if ((2 == chRd) || (5 == chRd))
        Serial.println(F("log-scale."));
    else if ((1 == chRd) || (4 == chRd))
        Serial.println(F("linear."));
    else
        Serial.println(szOff);
    Serial.print(F("Read Band Switch: "));
    if (globalConfig.featureEn[FEATURE_BAND_SW]) {
        Serial.print( globalConfig.numBandCfg +1 );
        Serial.println( F(" bands.") );
    } else
        Serial.println( szOff );
    Serial.print(F("Write Display: "));
    chRd = globalConfig.featureEn[FEATURE_DISPLAY];
    if (chRd) {
        Serial.print( F("rotate") );
        Serial.println( chRd );
    } else
        Serial.println( szOff );

#if BUILD_GUI_LIB
    chRd = tft.readcommand8(ILI9341_RDMODE);
    Serial.print(F("DisplayPwrMd: 0x")); Serial.println(chRd, HEX);

    chRd = tft.readcommand8(ILI9341_RDMADCTL);
    Serial.print(F(" MADCTL Mode: 0x")); Serial.println(chRd, HEX);

    chRd = tft.readcommand8(ILI9341_RDPIXFMT);
    Serial.print(F("Pixel Format: 0x")); Serial.println(chRd, HEX);

    chRd = tft.readcommand8(ILI9341_RDIMGFMT);
    Serial.print(F("Image Format: 0x")); Serial.println(chRd, HEX);

    chRd = tft.readcommand8(ILI9341_RDSELFDIAG);
    Serial.print(F("  Self Diag : 0x")); Serial.println(chRd, HEX); 
#endif

#if BUILD_RADIO && 1
     curBand = 0;
     do {
        UINT min, max;
        BAND_CFG * bandCfg = & globalConfig.bands[(int)curBand];
        cur_Mode = bandCfg->mode;
        if (NUM_MODES <= cur_Mode)
            cur_Mode = MODE_NOT_VALID;
        if (cur_Mode != MODE_NOT_VALID) {
            min = bandCfg->minFreq;
            max = bandCfg->maxFreq;
            currentFrequency = globalConfig.actFreq[(int)curBand];
            if (MODE_FM == cur_Mode) {
                min /= 10; max /= 10;
                currentFrequency /= 10;
            }
            Serial.print(F("Band"));   Serial.print(curBand + BAND_ONES_OFFSET, DEC);
            Serial.print(modeStrings[ (int)cur_Mode ]);
            Serial.print(F(" from ")); Serial.print(min);
            Serial.print(F(" to "));   Serial.print(max);
            Serial.print(F(" cur "));  Serial.print(currentFrequency);
            Serial.print(F(" bw ")); 
            if (MODE_FM == cur_Mode) {
                if (0 == bandCfg->bw) 
                    Serial.println(F("Auto")); 
                 else Serial.println( bandwidthFM[bandCfg->bw]);
            } else Serial.println(strBandwidthAM[bandCfg->bw]);
        }
        curBand ++;
     } while (curBand < NUM_BANDS);
    Serial.print(F("Active band "));   Serial.print(globalConfig.actBand + BAND_ONES_OFFSET, DEC);
    Serial.print(F(" out of "));   Serial.println(NUM_BANDS, DEC);
#endif
    print_help();

    do {
#if BUILD_RADIO || BUILD_GUI_LIB
        UINT desiredFreq = globalConfig.actFreq[ (int)globalConfig.actBand ];
#endif

#if BUILD_RADIO
        /* control the radio if globalConfig has changed */
        if ((curBand != globalConfig.actBand) || (0 != forceBand))
        {
            BAND_CFG * bandCfg;

            curBand = globalConfig.actBand;
            prev_mode_valid = mode_is_valid;
            mode_is_valid = false;
            if (NUM_BANDS > curBand) {
                bandCfg = & globalConfig.bands[(int)curBand];

                cur_Mode = bandCfg->mode;
                switch (cur_Mode) {
                    case MODE_AM:
                        Serial.print( F("Setting AM ") );
                        rx.setAM(bandCfg->minFreq, bandCfg->maxFreq, desiredFreq, 10);
                        rx.setBandwidth(bandCfg->bw, 1);
                        rx.setSeekAmLimits(bandCfg->minFreq, bandCfg->maxFreq);
                        rx.setSeekAmSpacing(10); // spacing 10kHz
                        goto mode_good;
                    case MODE_FM:
                        Serial.print( F("Setting FM ") );
                        rx.setFM(bandCfg->minFreq, bandCfg->maxFreq, desiredFreq, 20);
                        rx.setSeekFmSpacing(2);
                        goto mode_good;
                    case MODE_SSB:
                        Serial.print( F("Setting SSB ") );
                        rx.setAM(bandCfg->minFreq, bandCfg->maxFreq, desiredFreq, 5);
                        rx.setSeekAmLimits(bandCfg->minFreq, bandCfg->maxFreq);   // Range for seeking.
                        rx.setSeekAmSpacing(1); // spacing 1kHz
                    mode_good:
                        if ((bandCfg->minFreq <= desiredFreq) &&
                            (bandCfg->maxFreq >= desiredFreq)) {
                            mode_is_valid = true;
                            curVol = 0;         // force a volume update when mode is valid
                            break;
                        }
                        Serial.print( F("Freq not valid ") );
                        goto freq_not_valid;
                    case MODE_NOT_VALID:
                    default:
                        Serial.print( F("Mode not valid ") );
                    freq_not_valid:
                        if (prev_mode_valid) {
                            rx.setVolume(0);
                            Serial.println(F("- set vol 0"));
                        }
                        break;
                }
                Serial.println( (MODE_FM == cur_Mode) ? (desiredFreq / 10) : desiredFreq );
                delay(500);
            }
            forceBand = 0;
      //    currentFrequency = desiredFreq;
        } else
            currentFrequency = rx.getFrequency();
        if ((currentFrequency != desiredFreq) &&
            (mode_is_valid == true))
        {
            char cur_dir = 2, flip_count = 0;

            Serial.print( F("Tuning to ") );
            Serial.print( (MODE_FM == cur_Mode) ? (desiredFreq / 10) : desiredFreq );
            do  {
                if (5 < flip_count)
                {
                    Serial.print( F(" - failed at ") );
                    Serial.print( currentFrequency );
                    mode_is_valid = false;
                    break;
                }
                if (currentFrequency < desiredFreq)
                {
                    rx.frequencyUp();
                    if (1 != cur_dir)
                        flip_count ++;
                    cur_dir = 1;
                } else {
                    rx.frequencyDown();
                    if (0 != cur_dir)
                        flip_count ++;
                    cur_dir = 0;
                }
                currentFrequency = rx.getFrequency();
            } while (currentFrequency != desiredFreq);
            Serial.println(".");
        }

        if (curVol != globalConfig.actVolume)
        {
            rx.setVolume(curVol = globalConfig.actVolume);
            Serial.print(F("Setting volume "));
            Serial.println(curVol);
        }
#endif

        /* service the serial port - command line interface */
#if SOFT_SERIAL
        while (BLE_Serial.available())
        {
            char key = BLE_Serial.read();

            if ( ('\r' == key) || ('\n' == key) )
            {
                const char * resStr;
                ble_cmd_buffer[ble_cmd_in] = '\0';
                resStr = process_cmd_line(1);
                BLE_Serial.print(F("{"));
                BLE_Serial.write( resStr );
                BLE_Serial.write( fmt_rsp_buffer );
                BLE_Serial.print(F("}\n\r"));
                ble_cmd_in = 0;
            } else
            if ( // ('\n' != key) && (0x1B != key) &&
                (CMD_BUF_SIZE -1 > ble_cmd_in) ) {
                    ble_cmd_buffer[ble_cmd_in] = key;
            //      BLE_Serial.print(key);          // Echo !
                    ble_cmd_in ++;
            }
        }
#endif
        while (Serial.available())
        {
            char key = Serial.read();
            if ('\n' == key) {
                const char * resStr;
                dbg_cmd_buffer[dbg_cmd_in] = '\0';
                resStr = process_cmd_line(0);
                Serial.write( resStr );
                Serial.write( fmt_rsp_buffer );
                Serial.print('\n');
                dbg_cmd_in = 0;
            } else
            if (0x08 == key) {
                if (1 <= dbg_cmd_in) {
                    Serial.print('\r');
                    dbg_cmd_in --;
                    dbg_cmd_buffer[dbg_cmd_in] = '\0';
                    if (dbg_cmd_in)
                        Serial.write(dbg_cmd_buffer, dbg_cmd_in);
                }
            } else
            if (('\r' != key) && (0x1B != key) &&
                (CMD_BUF_SIZE -1 > dbg_cmd_in) ) {
                    if (('a' <= key) && ('z' >= key))
                        key -= ('a' - 'A');
                    dbg_cmd_buffer[dbg_cmd_in] = key;
                    Serial.print(key);          // Echo !
                    dbg_cmd_in ++;
            }
        }

        /* Implement the features if enabled in globalConfig */

        /* Feature 3:
         * change AM/FM Band based on a digital or analog input */
        if (globalConfig.featureEn[FEATURE_BAND_SW]) {
            char newBand = 0;
            A2D_VAL pinA1 = analogRead(analogBandSwitch);
            do {
                if (pinA1 < globalConfig.bndSwCal[(int)newBand])
                    break;
                newBand ++;
             } while (globalConfig.numBandCfg > newBand);
             /* ignore a value of zero here */
             if (0 < newBand) {
                newBand --;
                if (globalConfig.actBand != newBand)
                {
                    Serial.print(F("Band Sw now "));
                    Serial.println((int)newBand);
                    globalConfig.actBand = newBand;
                }
             }
        }
        /* Feature 1:
         * change frequency by doing a capacitence/timing measurement */
        if ((globalConfig.featureEn[FEATURE_FREQ_CAP]) &&
            (NUM_BANDS > curBand)) {      // Get cap, calc Frequency
            BAND_CFG * bandCfg = & globalConfig.bands[(int)curBand];
            FREQ_VAL newFreq;
            unsigned long bandFreq, offFreq;
            CAP_RD_VAL shortCnt, diff, tuner = measure_Cap_timing( false );

            bandFreq = bandCfg->maxFreq - bandCfg->minFreq;
            if ( globalConfig.tunerCal[1] > globalConfig.tunerCal[0]) {
                shortCnt = globalConfig.tunerCal[0];
                diff = globalConfig.tunerCal[1] - globalConfig.tunerCal[0];
            } else {
                shortCnt = globalConfig.tunerCal[1];
                diff = globalConfig.tunerCal[0] - globalConfig.tunerCal[1];
            }
            if (tuner > shortCnt)
                tuner -= shortCnt;
            else tuner = 0;
            offFreq = (bandFreq * tuner) / diff;
            if ( globalConfig.tunerCal[1] > globalConfig.tunerCal[0]) {
                newFreq = bandCfg->minFreq + (FREQ_VAL)offFreq;
            } else {
                newFreq = bandCfg->maxFreq - (FREQ_VAL)offFreq;
            }
#if 1
            {
                static UINT saveFrequency = 0;
                newFreq = roundToBandwidth(newFreq);
                if (saveFrequency != newFreq) {
                    Serial.print(F("Cal dif "));
                    Serial.print( diff );
                    Serial.print(F(" tuner "));
                    Serial.print(tuner);

                    Serial.print(F(" New freq "));
                    Serial.print( newFreq );
                    Serial.print(F(" offset "));
                    Serial.println(offFreq);

                    saveFrequency = newFreq;
                }
            }
#endif
#if 0
            currentFrequency = roundToBandwidth(newFrequency);
            if ( globalConfig.actFreq[(int)curBand] != currentFrequency) {
                Serial.print(F("Band Sw now "));
                Serial.println(currentFrequency);
                globalConfig.actFreq[(int)curBand] = roundToBandwidth();
            }
#endif
        }
        /* Feature 2:
         * change volume based on an analog input */
        if (globalConfig.featureEn[FEATURE_VOLUME]) {
            // Get Volume
            int pinA0 = analogRead(analogVolumePin);
            UCHAR newVol;

            switch (globalConfig.featureEn[FEATURE_VOLUME]) {
                case 3:         // opposite log scale
                    pinA0 = (MAX_ANALOG_VALUE - pinA0);
                case 6:         // opposite log scale upside down
                    newVol = MAX_VOLUME - pot_log_scale(pinA0);
                    break;

                case 5:         // log scale upside down
                    pinA0 = (MAX_ANALOG_VALUE - pinA0);
                case 2:         // log scale
                    newVol = pot_log_scale(pinA0);
                    break;

                case 4:         // linear upside down
                    pinA0 = (MAX_ANALOG_VALUE - pinA0);
                case 1:         // linear
                    newVol = (pinA0 * MAX_VOLUME) / (MAX_ANALOG_VALUE);
                    break;
            }
            if (((globalConfig.actVolume > newVol) && ((globalConfig.actVolume - newVol) > 4)) ||
                ((newVol > globalConfig.actVolume) && ((newVol - globalConfig.actVolume) > 4))) {
                Serial.print(F("New volume "));
                Serial.println(newVol);
            }
            globalConfig.actVolume = newVol;
        }
        /* Feature 4:
         * update a display for output */
#if BUILD_GUI_LIB
        if (globalConfig.featureEn[FEATURE_DISPLAY]) {
            // update the display
# if 1
            if ((curRotate != globalConfig.featureEn[FEATURE_DISPLAY]) &&
                (0 == scr_need_up))
            {
                curRotate = globalConfig.featureEn[FEATURE_DISPLAY]; // newRotate;
                tft.setRotation(ADA_LIB_ROTATE(curRotate));
                Serial.print(F("rotate ")); Serial.println(curRotate, DEC); 
                dispFreq = desiredFreq;
                scr_need_up = 1;
            }
            else
#endif
            if (dispFreq != desiredFreq)
            {
                Serial.print(F("freq")); Serial.println(desiredFreq, DEC); 
                dispFreq = desiredFreq;
#if 1
                if (0 == scr_need_up)
                {
                int adjust_y = FIRST_LINE_SIZE * 8 * 2;
                if (PORTRAIT_ROTATE(curRotate)) 
                    adjust_y += FIRST_LINE_SIZE * 8;
            //  tft.fill(BACKGROUND_COLOR);
                tft.rect(0, adjust_y, 
                            tft.Adafruit_SPITFT::width(),
                            SECOND_LINE_SIZE * 8);
                tft.setCursor(0, adjust_y);
                myText(2);  // re-draw second line
                } else
#endif
                if (2 != scr_need_up)
                    scr_need_up ++;
            }

            if (0 != scr_need_up) {
            if (MY_TEXT_NUM_STEPS > scr_line) {
                myText(scr_line);
                scr_line ++;
            } else {
                if (dbgText(scr_line - MY_TEXT_NUM_STEPS))
                {
                scr_line = 0;
        # if 1
                if (curRotate != globalConfig.featureEn[FEATURE_DISPLAY]) {
                    curRotate = globalConfig.featureEn[FEATURE_DISPLAY];
                    tft.setRotation(ADA_LIB_ROTATE(curRotate));
                }
        # endif
                scr_need_up --;
                } else
                scr_line ++;
            }
            }
        }
#endif
    } while (1);
}
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

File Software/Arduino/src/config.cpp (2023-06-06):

/* Load and Save configuration data in atomega328 EEPROM
*/

#include "select_build.h"
#include "arduino_radio.h"

#ifdef BUILD_APPLICATION

#if USE_EEPROM
#include <EEPROM.h>
#endif
#include "display.h"

#define NUM_LOG_STEPS   8
#define SIZE_LOG_STEP   ((MAX_ANALOG_VALUE + 1) / NUM_LOG_STEPS)

static const UCHAR log_offset[NUM_LOG_STEPS] =
    { 0, 32, 48, 56, 60, 62, 63, MAX_VOLUME };

UCHAR pot_log_scale(A2D_VAL volIn)
{
    int div, mod;
    UCHAR powTwo, baseOff;

    div = volIn / SIZE_LOG_STEP;
    mod = volIn % SIZE_LOG_STEP;

    powTwo =  2 + div;
    baseOff = log_offset[div];

    return (baseOff + (mod >> powTwo));
}  // potentiometer

FREQ_VAL roundToBandwidth(FREQ_VAL freqIn)
{
    BAND_CFG * bandCfg;
    FREQ_VAL result, minFre, spacing, diff;
    int curBand = globalConfig.actBand;

    bandCfg = & globalConfig.bands[curBand];
    result = freqIn;
    minFre = bandCfg->minFreq;
    if (MODE_FM == bandCfg->mode) {
        spacing = 20;      // commerical FM is 200 KHz spacing
        if ((0 < bandCfg->bw) && (NUM_BW_DEF_FM > bandCfg->bw))
            spacing = bandwidthFM[bandCfg->bw];
    } else {
        spacing = 1;        // assume 1 KHz spacing
        if ((0 < bandCfg->bw) && (NUM_BW_DEF_AM > bandCfg->bw))
            spacing = bandwidthAM[bandCfg->bw];
    }
    diff = result - minFre;
    if (MODE_FM == bandCfg->mode)
       diff = diff / spacing;
    else
        diff = (diff + (spacing / 2) -1) / spacing;
    result = minFre + (diff * spacing);
#if 0
    Serial.print( F("Input ") );
    Serial.print( freqIn );
    Serial.print( F(" round ") );
    Serial.println( result );
#endif
    if (result > bandCfg->maxFreq) {
        result = bandCfg->maxFreq;
        if (MODE_FM == bandCfg->mode)
            result -= spacing / 2;
    }
    else if (MODE_FM == bandCfg->mode) {
        result += spacing / 2;
    }
    return result;
}

/* Where in the EEPROM space do we start */
#define STARTING_LOCATION 0

CONFIG globalConfig;

static const CONFIG default_config {
    "VER-001",
    sizeof(CONFIG),
    0,              // first band
    (MAX_VOLUME * 2) / 3,
    0,              // number of positions in the band switch must be calibrated 
    {               // featureEn[]
        0,
        0,
        0,
        0 // == USE_EEPROM
    },
    {  10070, 1030, 0 },    // actFreq[]
    {               // bands[]
        { MODE_FM, 0, 8400, 10800 },
        { MODE_AM, 0,  520,  1750 },
        { MODE_NOT_VALID, 0, 0, 0 }
    },
    { 85, 255, 426, 597, 768 }, // tunerCal[5]
    { 0, MAX_ANALOG_VALUE } // bndSwCal[]
};

void save_config(void)
{
    write_config(0, sizeof(CONFIG));
}

void load_config(void)
{
#if USE_EEPROM
    char * cfg;
    UINT i;
    BOOL valid = true;

    Serial.print( F("Config size ") );
    Serial.println( sizeof(CONFIG) );

    // read everything we expect from the flash
    cfg = (char *) & globalConfig;
    for (i=0; i < sizeof(CONFIG); i++) {
        char ch = EEPROM.read( STARTING_LOCATION + i);
        * cfg = ch;
        cfg ++;
    }

# if 1
    // Is configuration valid?
    for (i=0; i < SIZE_OF_CONFIG_VERS; i++) {
        if (globalConfig.version[i] != default_config.version[i] ) {
            valid = false;
            Serial.println( F("Config fails version.") );
            break;
        }
    }
#  if 0
 /* if (0 > globalConfig.actBand) || */ 
    if (NUM_BANDS <= globalConfig.actBand) {
            valid = false;
            Serial.println( F("Config fails band.") );
    }
#  endif
    if (sizeof(CONFIG) != globalConfig.cfgSize) {
        Serial.print( F("Config has changed from ") );
        Serial.print( globalConfig.cfgSize );
        Serial.print( F(" to ") );
        Serial.println( sizeof(CONFIG) );
        valid = false;
    }

    if (false == valid) {
        memcpy( & globalConfig, & default_config, sizeof(CONFIG));
        save_config();
    }
# else
   // memcpy( & globalConfig, & default_config, sizeof(CONFIG));
# endif
#else
    memcpy( & globalConfig, & default_config, sizeof(CONFIG));
#endif
}

void write_config(UCHAR offset, UCHAR size)
{
#if USE_EEPROM
    char * cfg, ch;
    UINT i;
    if ((offset + size) <= sizeof(CONFIG)) {
        cfg = (char *) & globalConfig.version[offset];
        for (i=offset; i < (offset + size); i++ ) {
            ch = * cfg;
            EEPROM.write(STARTING_LOCATION + i, ch);
            cfg ++;
        }
    } 
    else {
        Serial.print( F("Write Config ") );
        Serial.print( offset );
        Serial.print( F(" plus ") );
        Serial.print( size );
        Serial.println( F(" not valid") );
    }
#endif
}
#endif  // #ifdef BUILD_APPLICATION - whole file

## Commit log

2022-04-25 Rev 3 Boards
    [Arduino controlled radio.kicad_pcb, Arduino controlled radio.sch]
2022-07-20 Initial upload of PC Client
    [Arduino Controlled Radio Default Control Pinouts.xlsx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]
2022-08-09 Added Serial I/O; Each band now has current frequency
2022-09-07 switch back to the ATMega processor, not my BLE Nano.
2022-09-28 fix MAX Volume, add an analog reference.
    [main.cpp]
2022-10-17 move towards new spec, calibration, band configuration not implemented.
2023-01-11 fix some last side-effects, like setting a valid freq when it had not been valid.
    [commands.cpp, main.cpp]
2023-01-18 Finish the one's base for band, only fail one time.
    [commands.cpp, main.cpp]
2023-03-06 First pass for calibration, needs to be tested with external hw.
2023-05-17 debugging band switch implementation, EEPROM issues
    [commands.cpp, config.cpp, main.cpp]
2023-05-30 minor band switch work
2023-05-31 always print analog val in Cal Band.

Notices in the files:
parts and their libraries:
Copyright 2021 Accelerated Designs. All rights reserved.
